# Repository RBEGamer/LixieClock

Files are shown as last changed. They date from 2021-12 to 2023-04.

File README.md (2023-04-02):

# LixieClock

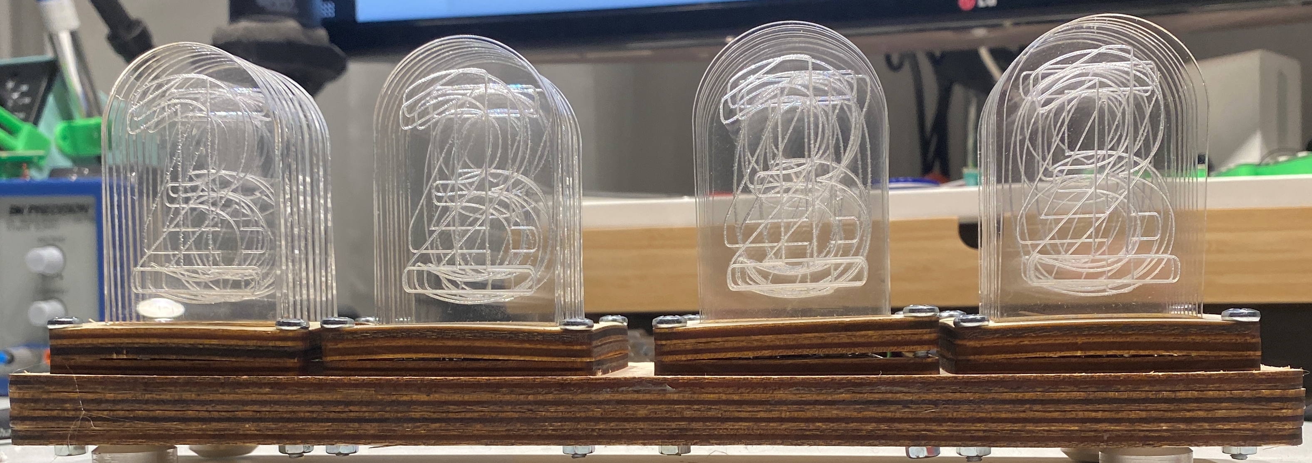
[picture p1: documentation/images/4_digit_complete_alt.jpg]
4_digit_complete_alt


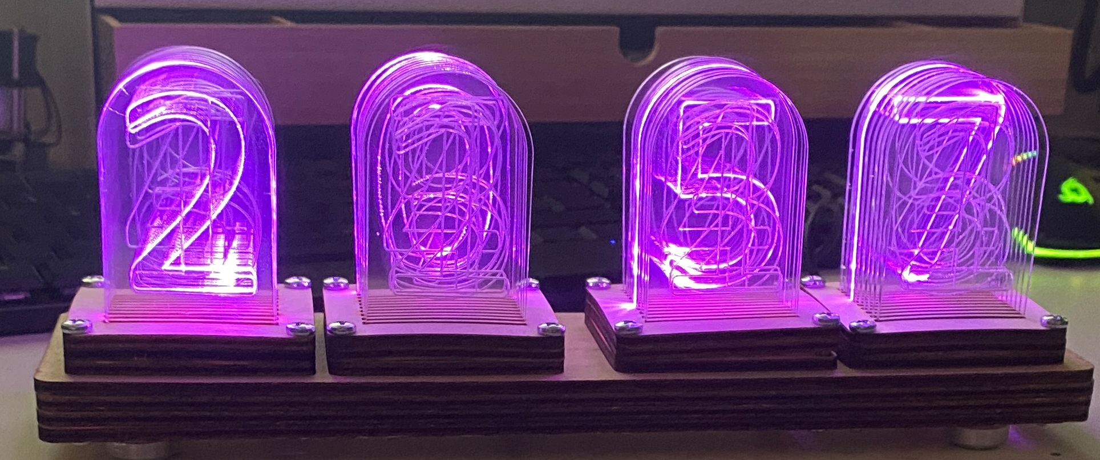
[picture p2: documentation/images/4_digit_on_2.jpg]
4_digit_on_2


# WERKZEUG

* Lötkolben + Lötzinn
* Philips-Kopf Schraubendreher
* Kleine Kabelbilder
* Heißkleber
* Glasreiniger
* Mikro-USB Kabel
* [OPTINAL] Holzkleber

# TEILELISTE

## BILD ZEIGT ALTE REVISION
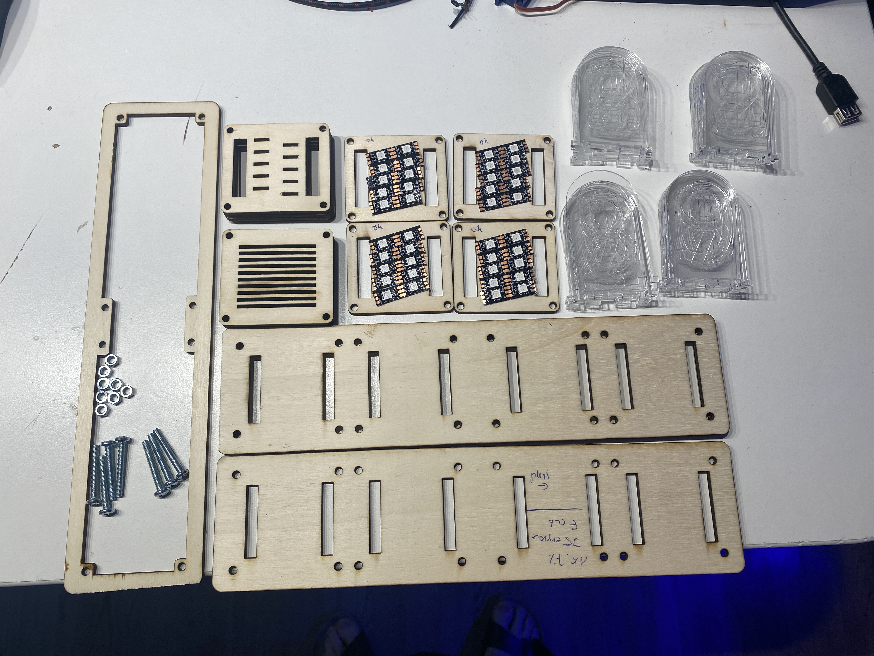
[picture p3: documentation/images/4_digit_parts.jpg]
4_digit_parts


## MECHANICAL

* LASERCUT TEILE `SVG - ./src/svg` oder `DXF - ./src/dxf`
* *  4x `4x_numbers_2mm_set_300_200_simplified` - acrylglas gs 2mm, engrave (blue lines), cut (red lines)
* *  1x `4_digit_combined_set_1` - playwood 4mm, engrave (blue lines), cut (red lines)
* *  1x `4_digit_combined_set_2` - playwood 4mm, engrave (blue lines), cut (red lines)
* *  1x `4_digit_combined_set_3` - playwood 4mm, engrave (blue lines), cut (red lines)

* 3D DRUCK
* * [OPTINAL] 4x `./src/3d_print/4x_lixie_feet.stl` - 0.2mm PLA

* MISC
* * 16x `M4x30 Philips Head Type PH2 - DIN7985`
* * 16x `M4 Nut - DIN934`
* * [OPTINAL] 4x `M4 THREAD INSERTS`

## ELECTRICAL

* 4x `LED_PCB`, SEE `./src/pcb`, LED SEITE BESTÜCKT
* 1x `ESP8266 D1 Mini`
* 8* `1*3 2.54mm  90° MALE HEADERS`
* 4x 3x`Jumperwires FEMALE<=>FEMALE`

## SOFTWARE 

* Arduino IDE

## BUILD INSTRUCTIONS

### 0. PROGRAMMIERUNG BASIS-PROGRAMM

Zum späteren Funktionstest wird hier zuerst der `ESP8266 D1 Mini` programmiert.
Somit kann die vollständige  Funktionalität vor dem finalen Zusammenbau überprüft werden.

Hierzu sollte die Arduino IDE installiert und dieses Git-Repository heruntergeladen sein.
Unter Linux kann dies wie folgt geschehen:

```bash
# ###### LINUX INSTALL ######
$ sudo apt update && sudo apt install -y git xz-utils

# CLONE REPOSITORY
$ cd ~ && git clone https://github.com/RBEGamer/LixieClock ./LixieClock

# INSTALL ARDUINO IDE
# # sudo snap install arduino => SEE NOTE!
$ wget https://downloads.arduino.cc/arduino-1.8.19-linux64.tar.xz
$ tar -xf arduino-1.8.19-linux64.tar.xz
$ cd arduino-1.8.19-linux64 && bash ./install.sh

# ALLOW USB COMMUNICATION
$ sudo usermod -a -G dialout $USER
$ sudo reboot
```

Nach dem Neustart kann der `ESP8266 D1 MINI` per USB Kabel mit dem Computer verbunden werden.

Das Demo-Programm der Uhr, welches eine vollständige über NTP Synchronisierte Uhr darstellt, benötigt einige Bibliotheken.
Diese könne über den Library-Manager der Arduino IDE installiert werden oder aus diesem Repository kopiert werden.
Unter Windows wird der Inhalt des Ordners `./src/required_libs` nach `BENUTZER_VERZEICHNIS/Dokumente/Arduino/libraries` kopiert.

Unter MacOS und Linux befindet sich der `Arduino`-Ordner direkt im Benutzer-Ordner `~/`.
Unter Linux muss aufgepasst werden, wie die Arduino IDE installiert wurde.
Wurde `snap install arduino` verwendet, befindet sich der Library-Order im Snap Verzeichnis `~/.snap/arduino/current/library`.

```bash
# ###### LINUX LIB COPY ######
$ cd ~
$ cp -Rf ./LixieClock/src/required_libs ~/Arduino/libraries
```

Anschließend kann die Arduino IDE geöffnet werden.

Unter `Datei -> Öffnen` kann das Programm geöffnet werden, dies befindet sich in diesem Repository unter dem Pfad `./src/lixieclock/lixieclock.ino`

Unter den Einstellungen muss danach zuerst der Support für den `ESP8266` geladen werden.
Hierzu wird unter dem Punkt `Zusätzliche Boardverwalter-URLs` die folgende Zeile hinzugefügt:

* `https://arduino.esp8266.com/stable/package_esp8266com_index.json`

#### NOTE

Falls ein `ESP32` verwendet wird muss diese hinzugefügt werden:

* `https://raw.githubusercontent.com/espressif/arduino-esp32/gh-pages/package_esp32_dev_index.json`

Allgemein ist die Software mit dem `ESP6266` (nicht `ESP6266-01`) und dem `ESP32` kompatibel.
#### END NOTE

Nach dem Speichern der Einstellungen muss das Board noch installiert werden.
Dazu wird unter `Werkzeuge -> Board -> Boardverwalter` der `ESP8266` installiert.
Anschlißend kann das `LOLIN (WEMOS) D1 MINI (CLONE)` als Board ausgewählt werden.

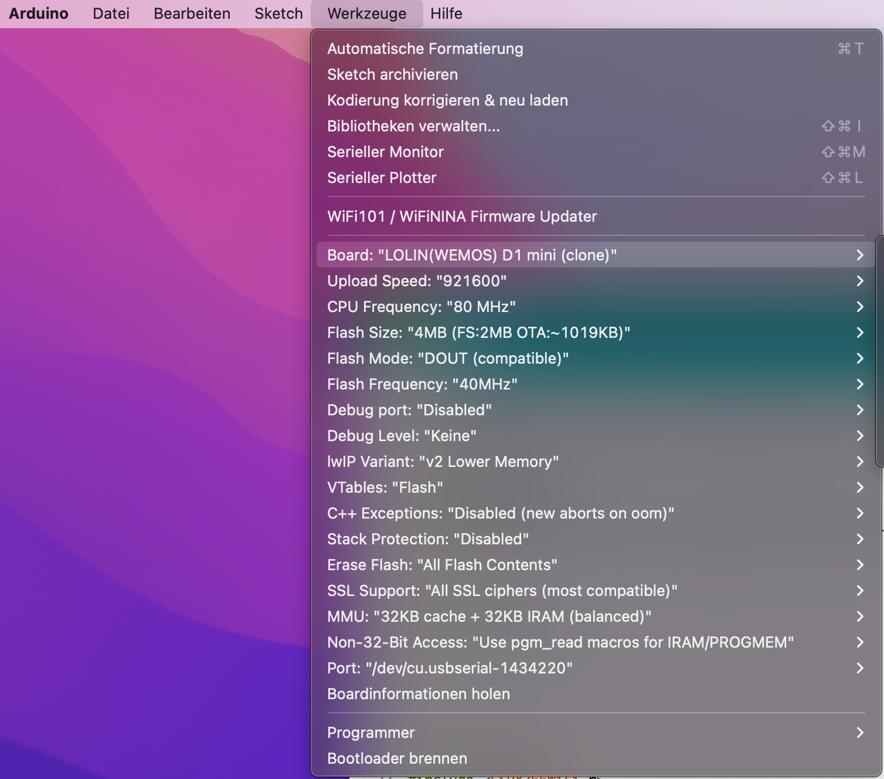
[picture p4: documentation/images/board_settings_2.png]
board_settings


Unter `Port` wird der Serielle-Port ausgewählt, an welchem sich das Board befindet.

* Windows `COMx`
* MacOS `/dev/ttyXXxxxXXxxx`
* Linux `/dev/ttyUSBx`

Anschließend kann über `Sketch -> Hochladen` das Programm hochgeladen werden.

#### NOTE

Im Verzeichnis `./src/lixieclock__base` befindet sich ein Demo-Programm, welches nur die einzelne Segmente ansteuert.
Dies kann als Basis für eigene Projekte verwendet werden.
Mittels der Funktion `update_clock_display` können alle Segmente der Uhr einzeln verändert werden.
Zur Bestimmung der Farbe können die Funktionen `Wheel` und `digit_color` verwendet werden.

```c++
void update_clock_display(int h, int m, int s, int col, int _bright, bool _disable_leading_zero);
uint32_t Wheel(int WheelPos, int _bright);
uint32_t digit_color(int _val,int _index, bool _banked, int _base_color, int _bright);
```

### 1. LED MODULE VORBEREITEN

**HINWEIS: Alle Sperrholzteile sind mit deren Namen markiert. Soweit nicht anders angegeben, zeigt diese nach oben.**

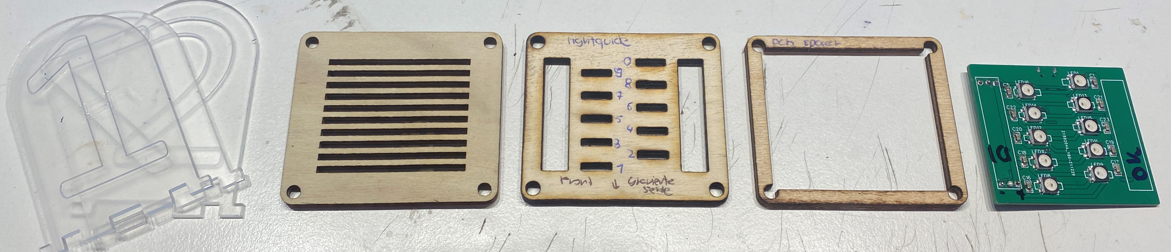
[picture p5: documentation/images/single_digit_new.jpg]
single_digit_new


Jedes LED Modul besteht aus drei Schichten:

* 4x jeweils 10x Acryglas Ziffern
* 4x jeweils 1x Sperrholz Ziffern-Halter
* 4x jeweils 1x Sperrholz Lightguide

Zuerst wird die Schutzfolien von den einzelnen Ziffern entfernt und 
ließend mit Glasreiniger entfettet.
**Ab jetzt dürfen die Ziffern nur noch an den Seiten angefasst werden, denn nach der Montage in der Halterung kommt man nur noch sehr schwer an die inneren Flächen der Ziffern.**

Jetzt werden sie einzelnen Ziffern in den `Ziffern-Halter` eingesetzt. Dabei müssen diese mit der gravierten Seite alle in die gleiche Richtung zeigen.
Auch ist die Reihenfolge wichtig, von hinten nach vorne, sind die Ziffern in dieser Reihenfolge einzusetzen:

`0` - `9`- `8` - `7` - `6` - `5` - `4` - `3` - `2` - `1`  

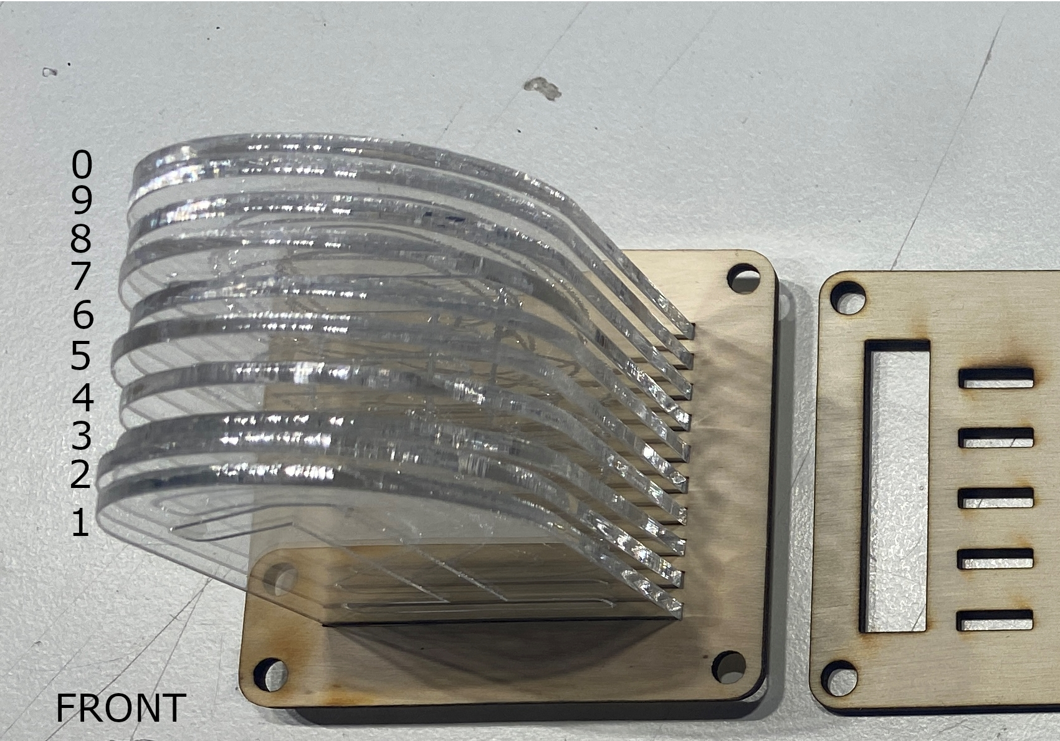
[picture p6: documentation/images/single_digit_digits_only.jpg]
single_digit_digits_only


Anschließend werden die Ziffern auf den `Lighguide` gesetzt.

**Dabei muss die gravierte Seite der Ziffern in Richtung der `FRONT` Markierung zeigen und die Markierungen auf dem `Lightguide` müssen mit den Ziffern übereinstimmen.**

Dieser Prozess, wird für alle vier Ziffern-Blöcke wiederholt.

#### NOTE

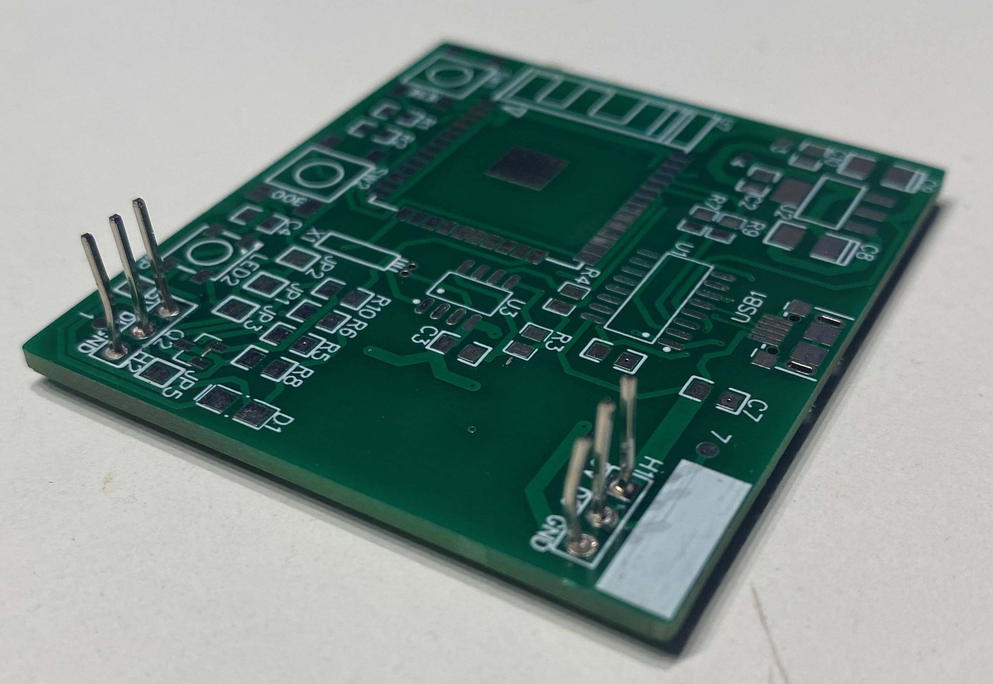
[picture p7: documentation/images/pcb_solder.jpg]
pcb_solder


Sollte bei den vier `LED-PCB`s die zwei Stiftleisten nicht bestückt sein, muss dies zuerst geschehen.
Dazu werden diese in die beiden vorgesehenen 1x3 Pin Bohrungen gesteckt. Diese sind auf der Platine mit `H1` und `H2` beschriftet.
Die lange Seite der Stiftleisten zeigt dabei von der LED Seite weg.

### 2. Zusammenbau Oberseite

Nachdem alle vier Module vorbereitet wurden, können diese nun mit der oberen Bodenplatte zusammengeschraubt werden.
Dabei wird zusätzlich auch die `LED_PCB` und der `PCB Spacer` benötigt.

* 4x PCB Spacer
* 4x LED_PCB mit Bestückter LED Seite
* 4x Top-Cover

Für den Zusammenbau wird das `TOP_COVER` mit der Beschriftung nach oben gelegt und die `LED-PCB`s jeweils mit den Stiftleisten in die Aussparungen des `TOP_COVER` gelegt, sodass die Platine flach aufliegt.

**WICHTIG** Die `FRONT` Markierung auf dem `TOP_COVER` und der Pfeil zeigt dabei zur Tischkante!

Diese werden dadurch nicht flach auf dem Tisch liegen, es empfiehlt sich das `TOP_COVER` dafür auf eine Tasse zu stellen.

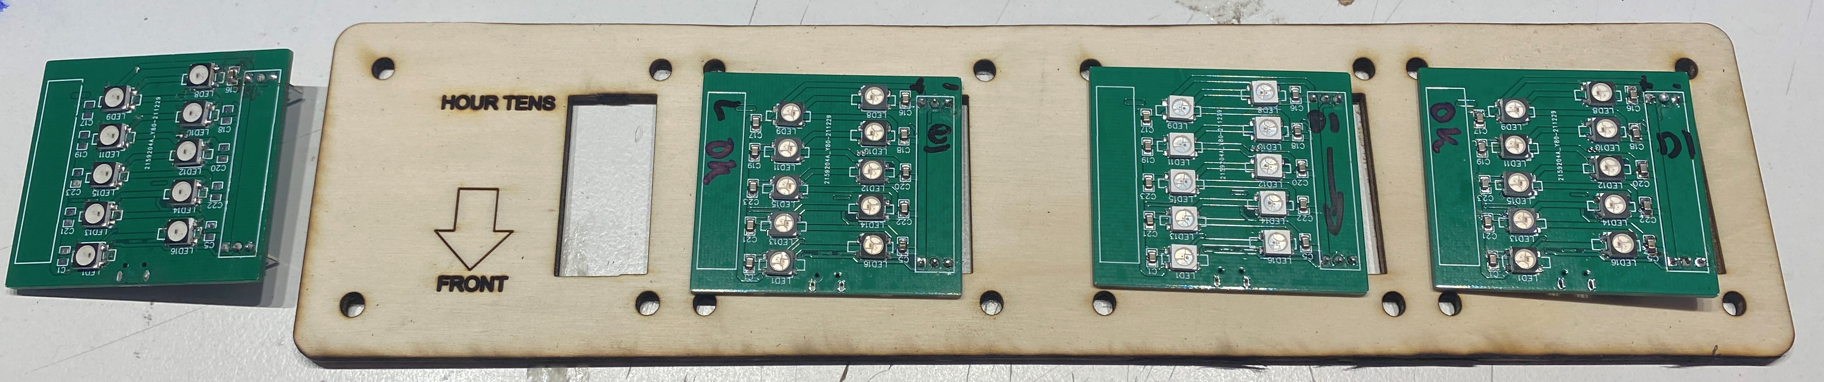
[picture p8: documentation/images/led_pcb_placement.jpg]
led_pcb_placement


Anschließend wird auf jede `LED_PCB` der Sperrholz `PCB_SPACER` gelegt, hier ist die Ausrichtung nicht relevant.

Als letztes, wird das im ersten Schritt zusammengebaute Ziffern-Modul auf den `PCB_Spacer` gesetzt.

**Dabei ist die Ziffer `1` die vorderste Ziffer (richtung der `FRONT` Markierung).**

Nach dem Platzieren der vier Ziffern-Module, sollten diese jeweils mit einer der `M40x30` Schrauben und `M4` Mutter gesichert werden.
Hier reicht es diese nicht fest anzuziehen. Dieser Schritt erleichtert die Montage im folgenden Schritt.

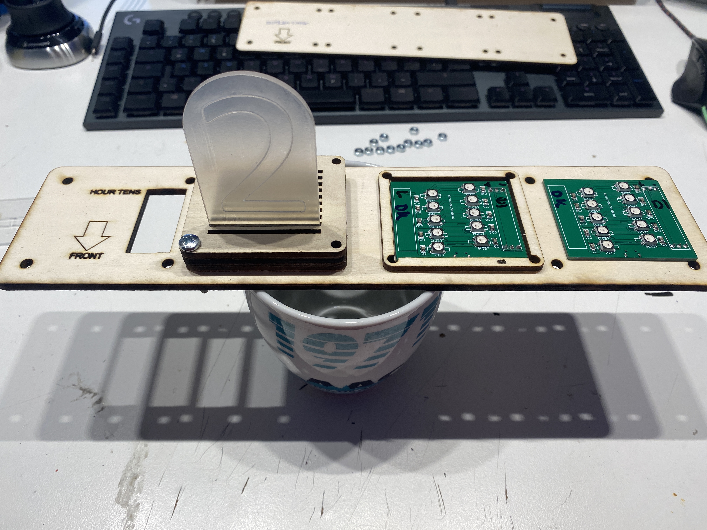
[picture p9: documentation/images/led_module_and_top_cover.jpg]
led_module_and_top_cover


### 3. Montage Bodenplatte

spacers

**Für diesen Schritt, wird alles umgedreht, sodass die LED Module mit der runden Seite auf der Tischplatte stehen.**
Die `FRONT` Markierung sollte jetzt in die andere Richtung Zeigen und somit das LED-Modul welches die Zehner-Stunden darstellen auf der linken Seite befindet.

Hier werden die folgenden Sperrholzteile benötigt:

* 1x `SPACER_TOP`
* 1x `SPACER_BOTTOM`

Diese dienen als Abstandshalter zwischen des `TOP_COVERS` und der Bodenplatte `BOTTOM_COVER`.
Am `SPACER_BOTTOM` befindet sich eine Aussparung für den `ESP8266 D1 MINI`.

#### OPTINAL 
Da diese beiden Teile leicht zerbrechlich sind bietet es sich an, diese mit etwas Holzleim zu verkleben.

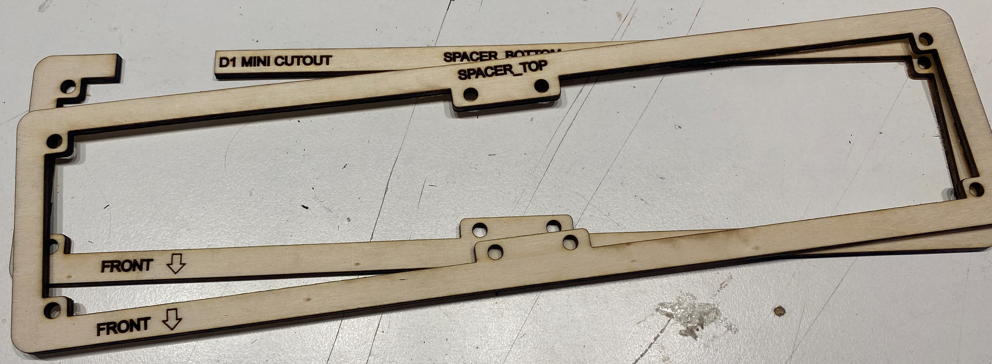
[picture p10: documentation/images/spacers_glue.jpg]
spacers_glue


Dabei wird der  `SPACER_TOP` auf den `SPACER_BOTTOM` geklebt und zu einfachen Arretierung dieser mit zwei Schrauben (oder Wäscheklammern) für 5 Minuten fixiert.
Nach dieser Zeit können diese wieder gelöst werden.

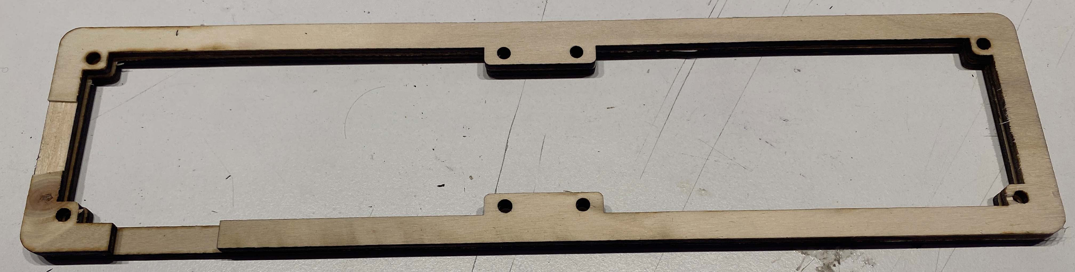
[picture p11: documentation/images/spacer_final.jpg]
spacer_final


#### END OPTIONAL

Die Schrauben (aus Schritt 2), welche die Module gehalten haben können jetzt wieder gelößt werden.

Die beiden Spacer (geklebt oder nicht), werden anschließend auf das `TOP_COVER` gesetzt, sodass sich die Aussparung unten links in der Ecke befindet und sich somit auf der Rückseite der Uhr befindet.
Anschließend können die Module wieder mit je einer Schraube fixiert werden. Somit sollten auch die beiden Spacer fixiert sein.

### 4. Montage Elektronik

Für die Verkabelung und Montage der Elektronik, wird alles umgedreht, sodass die LED Module mit der runden Seite auf der Tischplatte stehen.
Die `FRONT` Markierung sollte jetzt in die andere Richtung Zeigen und somit das LED-Modul welches die Zehner-Stunden darstellen auf der linken Seite befinden.
Für diesen Schritt werden die `Jumper-Wires`, sowie der `ESP8266 D1 MINI` benötigt.

Jetzt werden mit den 4x drei `Jumper-Wires` die einzelnen Module miteinander Verbunden. Auf den `LED-PCB`s sollten die Stiftleisten durch das `TOP_COVER` zugänglich sein. Bei diesen sind die einzelnen Pins beschriftet. Für `H1 => 5V D0 GND` und für `H2 => 5V DIN GND`.
Das Ziel ist es die einzelnen Platinen zu einer Kette zu verbinden. 
Angefangen von der Zehner-Stunden, wird die `H2`-Stiftleiste über drei `Jumper-Wires` mit der `H1`-Stiftleiste des Stunden-Einer-Moduls verbunden.
Dabei wird `5V->5V`, `GND->GND` und `DI->D0` verbunden.
Dieser Prozess wird anschließend noch zweimal wiederholt:

* Stunden-Zehner `H2` => Stunden-Einer `H1`
* Stunden-Einer `H2` => Minuten-Zehner `H1`
* Minuten-Zehner `H2` => Minuten-Einer `H1`

Nach diesem Schritt sind die Stiftleisten `Stunden-Zehner H1` und `Minuten-Einer H2` nicht verbunden.
Im letzten Schritt wird der `ESP8266 D1 Mini` mit der `Stunden-Zehner H1` verbunden.
Dabei werden die folgenden Pins am `ESP8266 D1 Mini` verbunden:

* `(ESP8266 D1 MINI) 5V` => `(Zehner Stunden H1) 5V`
* `(ESP8266 D1 MINI) D8` => `(Zehner Stunden H1) DIN`
* `(ESP8266 D1 MINI) GND` => `(Zehner Stunden H1) GND`

Anschließend kann vor dem finalen Zusammenbau die Funktion getestet werden.
Mit einem USB-Kabel wird der `ESP8266 D1 Mini` verbunden. Jede Ziffer sollte einmal aufleuchten.
Falls dies nicht der Fall ist, ist die Verkabelung zu Prüfen.

Um den Zusammenbau zu vereinfachen, werden die einzelnen Stiftleisten mit dem `Jumperwires` leicht zueinander (ca. 45°) gebogen und mit Heisskleber fixiert.
Auch die Kabel zwischen den Elementen werden mit Kabelbindern und/oder Heißkleber an der `TOP_PLATE` fixiert.

electric_complete

### 5. Endmontage

Im letzten Schritt wird der `ESP8266 D1 Mini` in die Aussparung des Spacers mit Heißkleber geklebt, sodass der USB-Anschluss nach aussen zeigt.
Geklebt wird auf der glatten Seite des `ESP8266 D1 Mini` (auf der gegenüberliegenden Seite des USB-Anschluss).

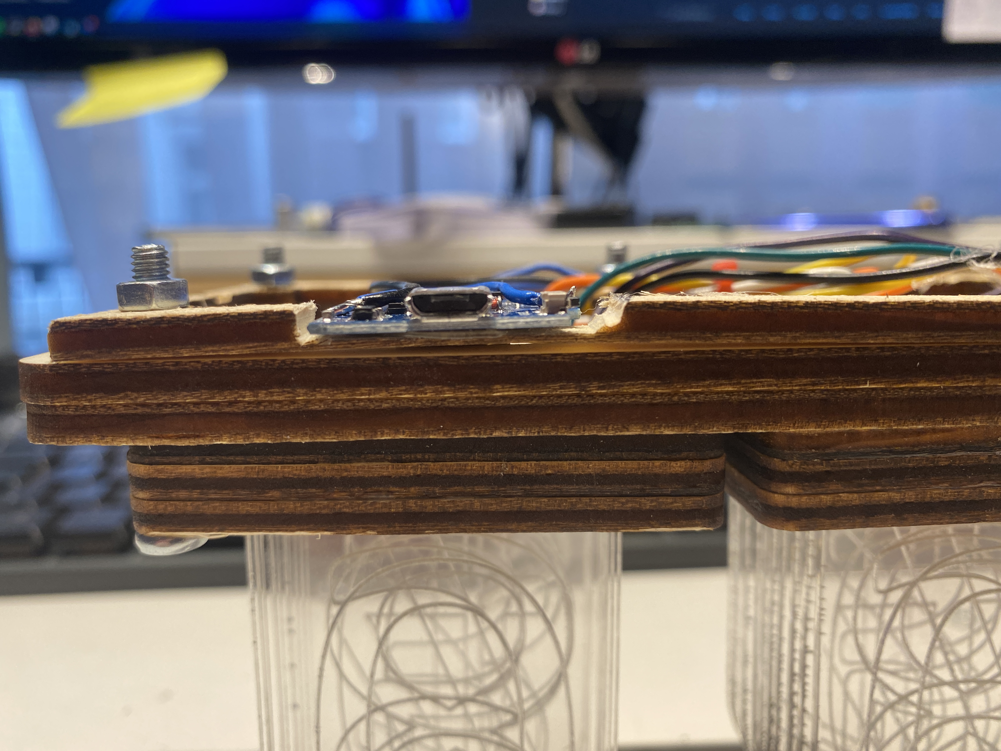
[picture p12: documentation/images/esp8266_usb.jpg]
esp8266_usb


Final kann die Bodenplatte `BOTTOM_COVER` montiert werden. Dazu werden die zuvor zur Montage genutzten Schrauben wieder gelöst und das `BOTTOM_COVER` auf die Spacer gelegt. Alle Schrauben werden dann handfest angezogen.

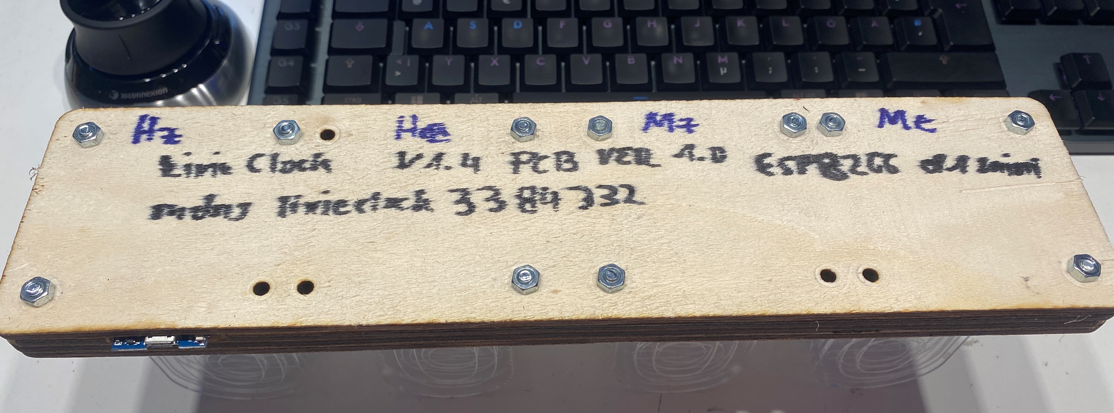
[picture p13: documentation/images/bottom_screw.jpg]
bottom_screw


#### OPTIONAL

Anstatt der vier M4 Muttern an den Ecken können auch die 3D gedruckten Füße angeschraubt werden.
Dazu werden die  `M4 THREAD INSERTS` mit dem Lötkolben erwärmt und in die Bohrung des Fußes bündig einschmelzen.
Nach dem Abkühlen können die Muttern an den Ecken ersetzt werden.

lixie_feet

### 6. Bedienung und Ersteinrichtung

Wenn die Uhr mit dem Basis-Programm programmiert wurde, agiert diese nach dem Starten als NTP-Synchronisierte Uhr.
Hierzu wird ein WLAN benötigt, mit welchem die Uhr einen Zeitserver abgragen kann.
Um dieses WLAN festzulegen, wird die Uhr normal mit Spannung versorgt. Mit einem anderen Endgerät z.B. dem Handy kann sich mit dem WLAN-Access-Point der Uhr verbunden werden.

Die WLAN-Konfigurations-Website ist nach dem Start der Uhr für 120 Sekunden sichtbar.

**Der aktive Access-Point wir vonder Uhr mit `00:00:00` angezeigt!**

Dieses heißt `LixieClockConfiguration_xxXXxxXX`. Nach dem Verbinden mit diesem öffnet sich eine Konfigurationsübersicht, in der das WLAN gesetzt werden kann.
Falls sich die Konfigutationsseite nicht automatisch öffnet (z.B. auf einem PC), kann die IP `http://192.168.4.1/` in einem Browser angegeben werden.

**Achtung** Nur 2.4 Ghz Netzwerke werden vom `ESP8266` und `ESP32` unterstützt.

**Bei einer fehlerhaften Verbindungsaufbau zeigt das Display der Uhr `42:42:42` an.**
Wenn dies der Fall ist, kann die Uhr neugstartet werden und die Konfiguration kann erneut durchgeführt werden.

Nach einer erfolgreichen Verbindung, zeigt die Uhr ihre IP-Adresse auf den einzelnen Ziffern per Laufschrift an.
Wird diese Adresse in einem Browser aus dem gleichen Netz aufgerufen, kann diese umfassend konfiguriert werden.

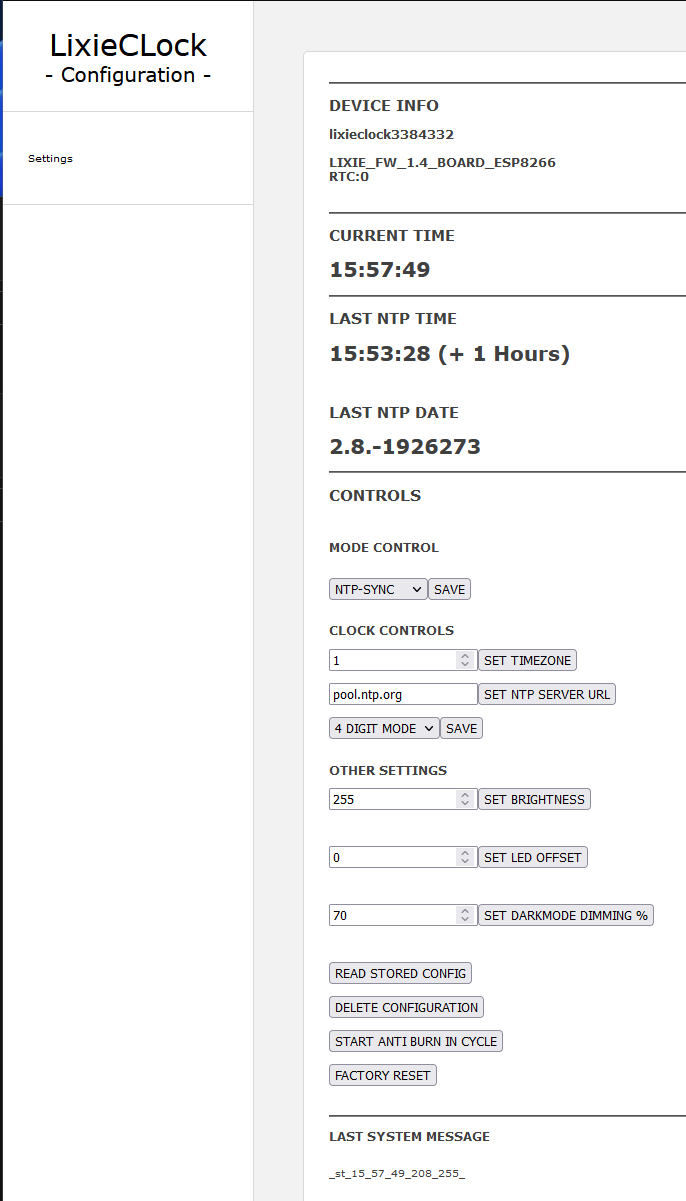
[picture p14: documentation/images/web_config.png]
web_config


# Troubleshooting

## Ziffern 3,4 und 7,8 sind getauscht

Dann hast du eine Platine der ersten Version verwendet. Diese hat einen Fehler in der Platzierung der LEDs bzw. deren Reihenfolge.
Dieser Fehler kann einfach per Software behoben werden. 
In der beigliegenden Demo-Software `/src/lixieclock` und `/src/lixieclock_base` gibt es ein passendes Makro welches gesetzt werden kann.

```c++
10 | #define PCB_V1_FIX //FIX DIGIT 3,4 and 7,8 SWAPPING ERROR ON PCB_V1 
```

## Ziffern sind um eine Stelle vertauscht

Wenn alle Ziffern um eine Stelle nach hinten verschoben ist, dann ist die Entwicklungsversion der Uhr bevor diese als Bausatz konzepiert wurde.
Hier existiert eine Error-LED auf der Platine, somit gibt es eine zusätzliche LED bei der Berechnung des LED-Index.
Hierzu bietet die Software ein Define, welches diesen Fehler behebt.

```c++
9 | #define PCB_V0_FIX //ON THE ESP8266 VERSION OF PCB V0 IS THE ERROR LED PRESENT
``` 

## Wordclock

Die Software-Version `>=2.0` unterstützt zusätzlich die Anordnung der LEDs als `Wordclock`.
Wenn nicht die richtigen Wörter aufleuchten, muss die Software für die Verwendung als Wordclock angepasst werden.

```c++
11 | #define WORDCLOCK_V0 // german wordclock layout
```

## RTC Offline-Mode 

Falls keine Internetverbindung bestehen sollte, kann die Uhr auch im Offline-Modus verwendet werden.
Dazu wird eine RTC Modul `DS1307` oder `DS3231` am I2C Bus des Controllers angeschlossen.
Zusätzlich muss der Software-Support aktiviert werden.
Die RTC wird automatisch durch den NTP-Server gestellt/aktualisiert, wenn eine Internetverbindung vorhanden ist.

```c++
14 | #define ENABLE_RTC
```

## ESP32 Version speichert Konfiguration nicht

Je nach verwendeter Arduino-IDE Version, sowie der verwendeten Libraries kann es bei der ESP32 Software zu Fehlern mit dem Dateisystem FS kommen.
Hierzu gib es eine neue Version `LitteFS`, welche die Default-Version `Filesystem` ersetzt.
Mittels Flag kann erzwungen werden, dass die neue `LittleFS` Bibliothek verwendet werden soll.

```c++
7 | #define USE_LITTLEFS
```

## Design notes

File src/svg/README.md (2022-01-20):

# SVG

This folder contains all svg files for lasercutting all needed peaces for a single digit or a complete clock.

## LASERCUTTING PASSES

* CUTTING `C` RED LINE IN SVG - (K40 SETTINGS 16%, 10mm/s)
* ENGRAVING `E` BLUE LINE IN SVG - (K40 SETTINGS 16%, 40mm/s)

## MATERIAL

* `A` - Plexiglas/Acrylglas GS 2mm
* `P` - Playwood 3mm

## SINGLE DIGIT

* 1x `4x_top_cover` - P, C
* 1x `4x_pcb_spacer` - P, C
* 1x `4x_bottom` - P, C
* 1x `4x_lightguide_top` - P, C
* 1x `4x_numbers_2mm_set_300_200` - A,  E + C

## CLOCK 4 DIGITS
### 200x300mm

* 4x `4x_numbers_2mm_set_300_200` -  A, E + C
* 1x `4_digit_combined_set_1` - P, C
* 1x `4_digit_combined_set_2` - P, C
* 1x `4_digit_combined_set_3` - P, C

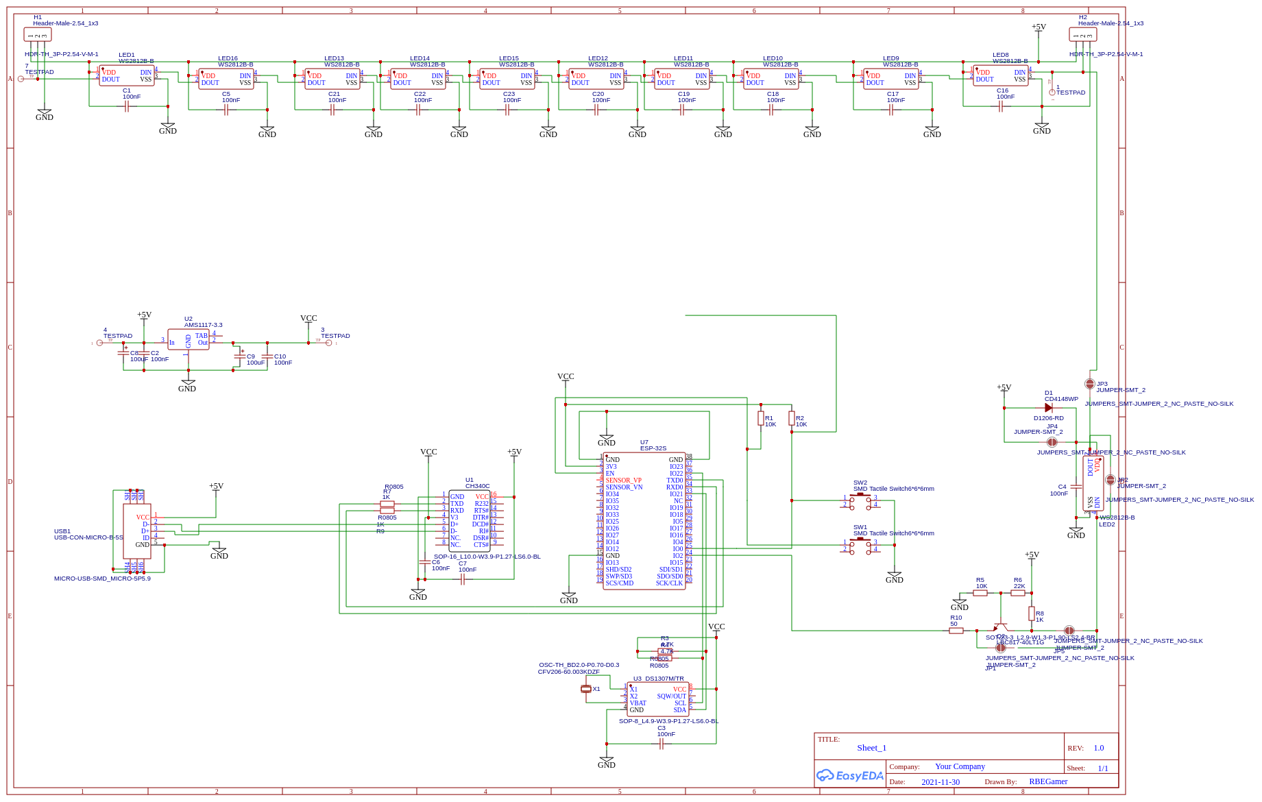
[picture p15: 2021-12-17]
src/pcb/LIXIE_PCB_V1/images/Schematic_LixieClock75x50_2021-12-17.png

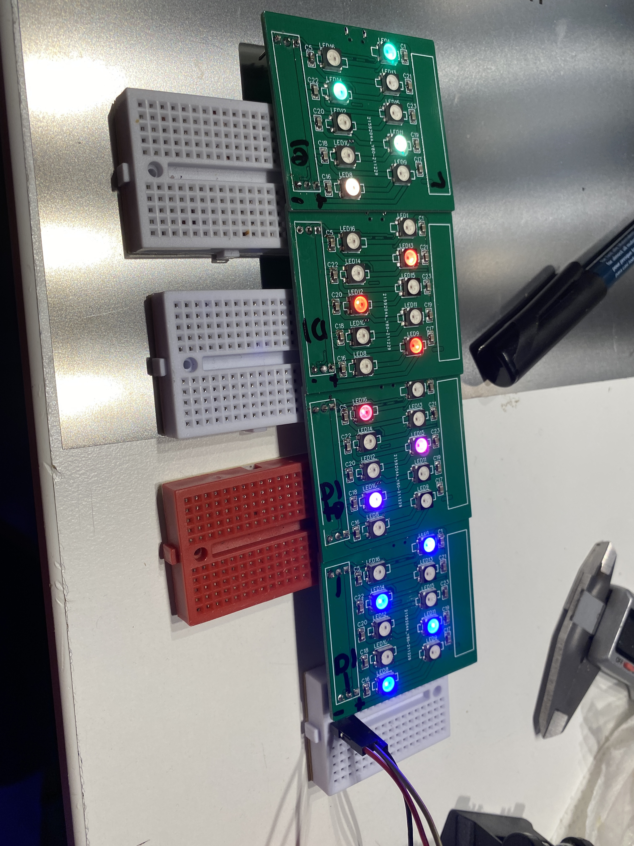
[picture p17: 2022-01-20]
documentation/images/2022-01-08 19.33.17.jpg

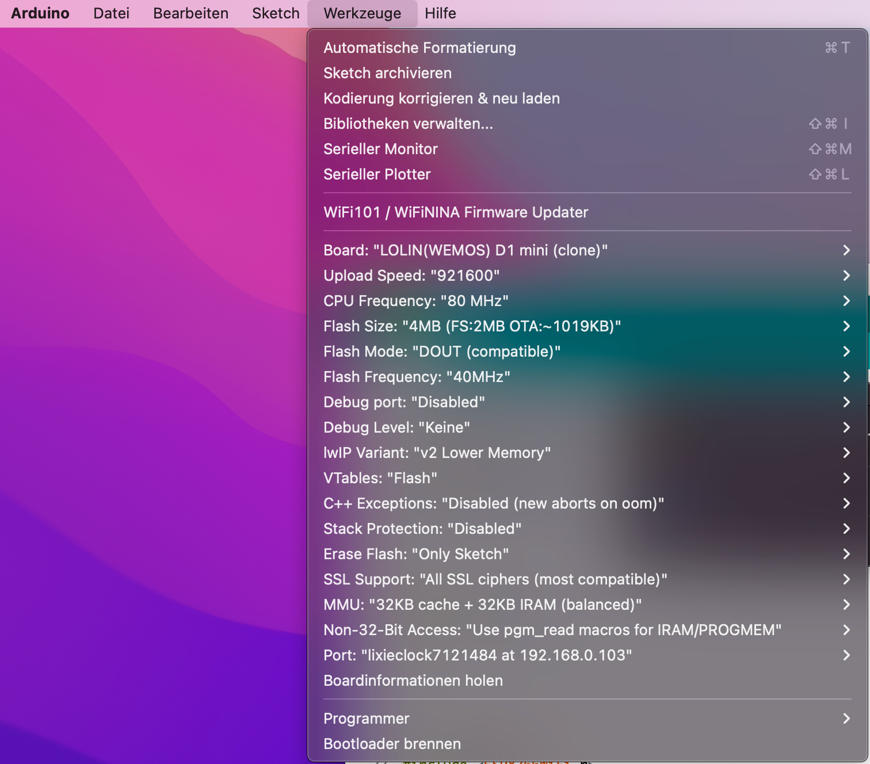
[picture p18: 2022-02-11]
documentation/images/board_settings.png

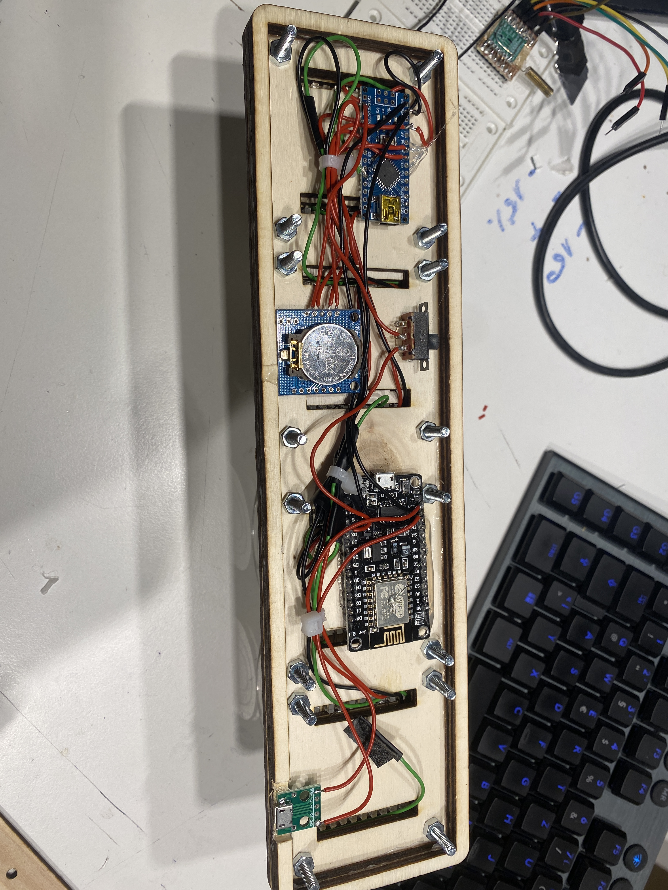
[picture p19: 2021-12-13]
documentation/images/2021-12-09 21.39.20.jpg

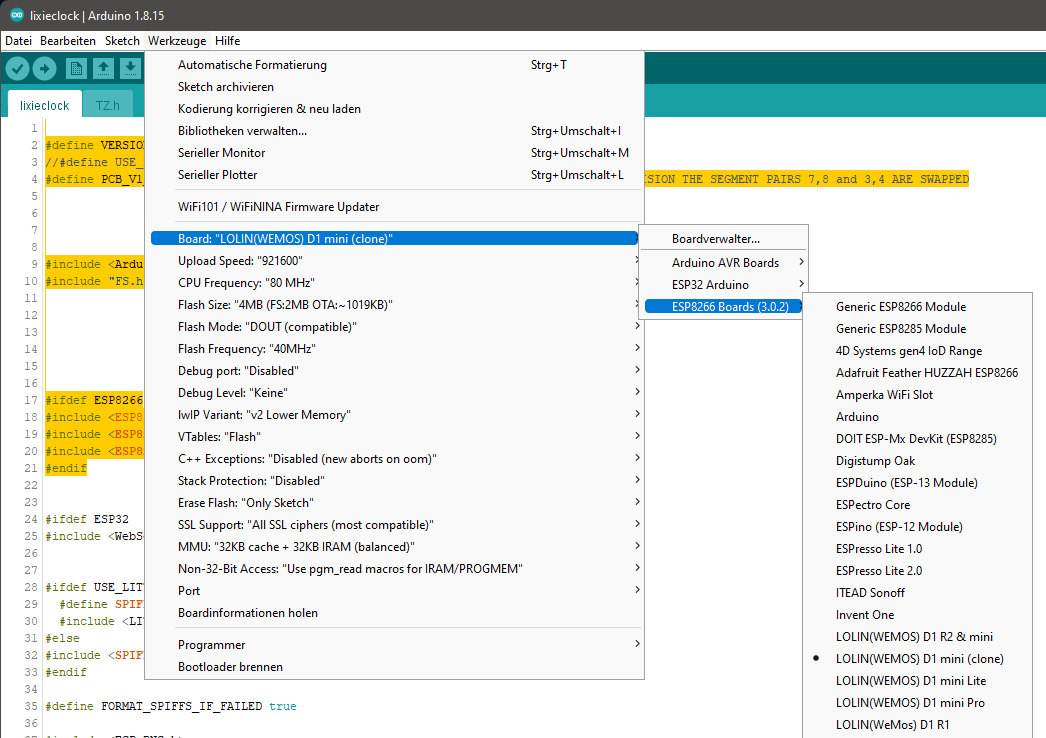
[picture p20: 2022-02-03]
documentation/images/sw_sel_board.png

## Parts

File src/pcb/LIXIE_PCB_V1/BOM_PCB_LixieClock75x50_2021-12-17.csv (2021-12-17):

ID | Name | Designator | Footprint | Quantity | Manufacturer Part | Manufacturer | Supplier | Supplier Part | Price | Pins | 3DModel | JLCPCB Part Class | LCSC Assembly | Contributor | Package Display | SMT Type | image | link
1 | USB-CON-MICRO-B-5S | USB1 | MICRO-USB-SMD_MICRO-5P5.9 | 1 | USB-CON-MICRO-B-5S | ValuePro | LCSC | C40954 | 0.063 | 11 | MICRO-USB-SMD_MICRO-5P5.9 | Extended Part |  | 立创EDA官方封装库 | Yes |  |  | https://item.szlcsc.com/41938.html
2 | TESTPAD | 1,3,4,7 | TESTPAD | 4 |  |  |  |  |  | 1 |  |  |  | Time God
3 | 100nF | C2,C10,C3,C4,C6,C7,C1,C5,C16,C17,C18,C19,C20,C21,C22,C23 | 0805 | 16 | CC0805KRX7R9BB104 | YAGEO | LCSC | C49678 | 0.004 | 2 |  |  | Yes | SparkFun |  | Basic
4 | 10K | R1,R2,R5 | 0805 | 3 | 0805W8F1002T5E | UniOhm | LCSC | C17414 | 0.002 | 2 |  |  | Yes | SparkFun |  | Basic
5 | 22K | R6 | 0805 | 1 | CR0805J22KP05 | Ever Ohms Tech | LCSC | C245415 | 0.002 | 2 |  |  | Yes | SparkFun |  | Basic
6 | 1K | R8 | 0805 | 1 | FCM2012KF-102T04 | TAITEC | LCSC | C155076 | 0.007 | 2 |  |  | Yes | SparkFun |  | Basic
7 | 50 | R10 | 0805 | 1 | 0805W8F1002T5E | UniOhm | LCSC | C17414 | 0.002 | 2 |  |  | Yes | SparkFun |  | Basic
8 | 100uF | C9,C8 | CAP-SMD_L3.5-W2.8 | 2 | TAJB107K006RNJ | AVX | LCSC | C16133 | 0.181 | 2 | CASE-B_L3.5-W2.8-H1.9 |  | Yes | 立创EDA官方封装库 |  | Basic |  | https://item.szlcsc.com/19983.html
9 | Header-Male-2.54_1x3 | H1,H2 | HDR-TH_3P-P2.54-V-M-1 | 2 | Header2.54mm 1*3P | BOOMELE | LCSC | C49257 | 0.013 | 3 | HDR-M-2.54_1x3 | Extended Part |  | 官方封装库 | Yes |  |  | https://item.szlcsc.com/50265.html
10 | AMS1117-3.3 | U2 | SOT-223_L6.5-W3.5-P2.30-LS7.0-BR | 1 | AMS1117-3.3 | AMS | LCSC | C6186 | 0.159 | 4 | SOT-223-4P_L6.5-W3.5-H1.6-LS7.0-P2.30 |  | Yes | 官方封装库 |  | Basic | //image.lceda.cn/szlcsc/C6186.jpg | https://item.szlcsc.com/109711.html
11 | ESP-32S | U7 | WIFIM-SMD_ESP-32S | 1 | ESP-32S | Ai-Thinker | LCSC | C82899 | 3.934 | 39 | WIFIM-SMD_L25.5-W18.0-H3.1-ESP-32S |  |  | LCSC |  |  |  | https://item.szlcsc.com/84060.html
12 | WS2812B-B | LED2,LED1,LED8,LED9,LED10,LED11,LED12,LED13,LED14,LED15,LED16 | LED-5050_4P | 11 | WS2812B-B | Worldsemi | LCSC | C114586 | 0.095 | 4 |  |  |  | LCSC
13 | 1K | R7,R9 | R0805 | 2 | FCM2012KF-102T04 | TAITEC | LCSC | C155076 | 0.007 | 2 | R0805_L2.0-W1.3-H0.6 | Extended Part |  | LCSC | Yes |  |  | https://item.szlcsc.com/142685.html
14 | CH340C | U1 | SOP-16_L10.0-W3.9-P1.27-LS6.0-BL | 1 | CH340C | WCH | LCSC | C84681 | 0.689 | 16 | SOP-16_L9.9-W3.9-H1.5-LS6.0-P1.27 | Extended Part |  | 官方封装库 | Yes |  |  | https://item.szlcsc.com/391677.html
15 | DS1307M/TR | U3 | SOP-8_L4.9-W3.9-P1.27-LS6.0-BL | 1 | DS1307M/TR | HGSEMI | LCSC | C356706 | 0.457 | 8 | SOP-8_L4.9-W3.9-H1.45-LS6.0-P1.27 | Extended Part |  | LCSC | Yes |  |  | https://item.szlcsc.com/383602.html
16 | CFV206-60.003KDZF | X1 | OSC-TH_BD2.0-P0.70-D0.3 | 1 | CFV206-60.003KDZF | CITIZEN | LCSC | C389957 | 0.206 | 2 | OSC-TH_D2.0-W6.0-P0.70 | Extended Part |  | LCSC | Yes |  |  | https://item.szlcsc.com/94424.html
17 | LBC817-40LT1G | Q2 | SOT-23-3_L2.9-W1.3-P1.90-LS2.4-BR | 1 | LBC817-40LT1G | LRC | LCSC | C12767 | 0.017 | 3 | SOT-23-3P_L2.9-W1.3-H1.0-LS2.4-P0.95 | Extended Part |  | 立创EDA官方封装库 | Yes |  |  | https://www.diodes.com/assets/Package-Files/SOT23.pdf
18 | 4.7K | R3,R4 | R0805 | 2 | RMC08054.7K5%N | Tyohm | LCSC | C269733 | 0.004 | 2 | R0805_L2.0-W1.3-H0.6 | Extended Part |  | LCSC | Yes |  |  | https://item.szlcsc.com/142685.html
19 | SMD Tactile Switch6*6*6mm | SW1,SW2 | SW-SMD_4PIN-L6.00-W6.00 | 2 | SMD Tactile Switch6*6*6mm | ReliaPro | LCSC | C23873 | 0.018 | 4 |  |  |  |  |  |  | http://image.lceda.cn/szlcsc/C23873.jpg | https://lcsc.com/product-detail/Tactile-Switches_Made-in-China-6x6x6-6-6-6mm_C23873.html
20 | CD4148WP | D1 | D1206-RD | 1 | CD4148WP | LIZ | LCSC | C109000 | 0.012 | 2 | D1206_L3.2-W1.5-H0.9 | Extended Part |  | 官方封装库 | Yes |  |  | https://item.szlcsc.com/110221.html

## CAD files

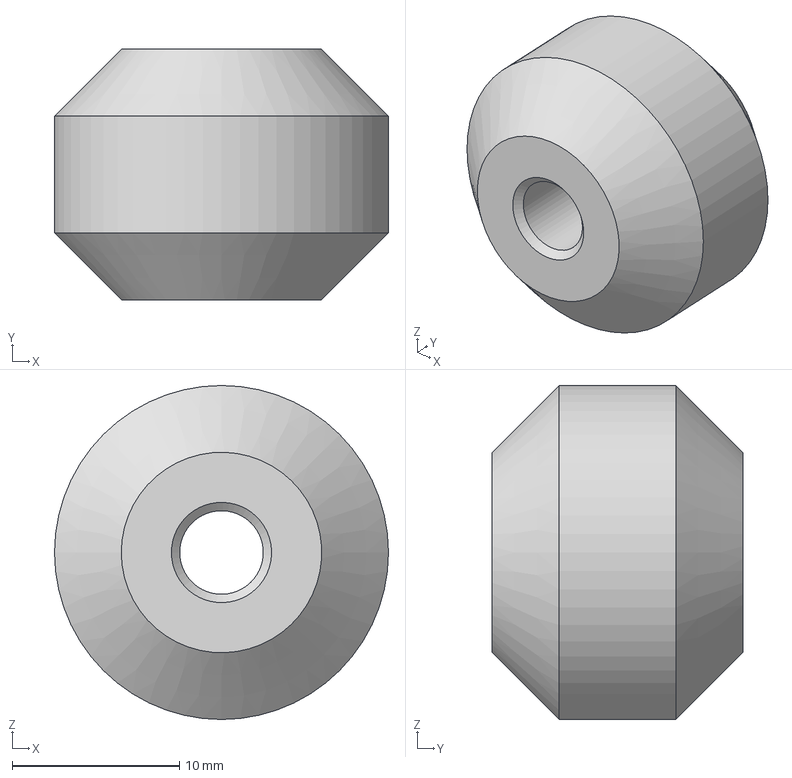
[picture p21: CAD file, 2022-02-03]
src/3d_print/4x_lixie_feet.step
20.0 x 15.0 x 20.0 mm

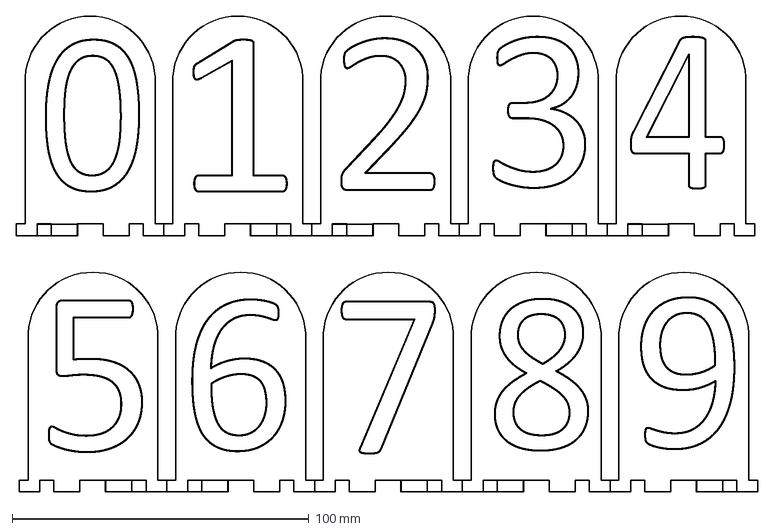
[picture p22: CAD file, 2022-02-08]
src/dfx/4x_numbers_2mm_set_300_200_simplified.dxf
249.7 x 160.3 mm

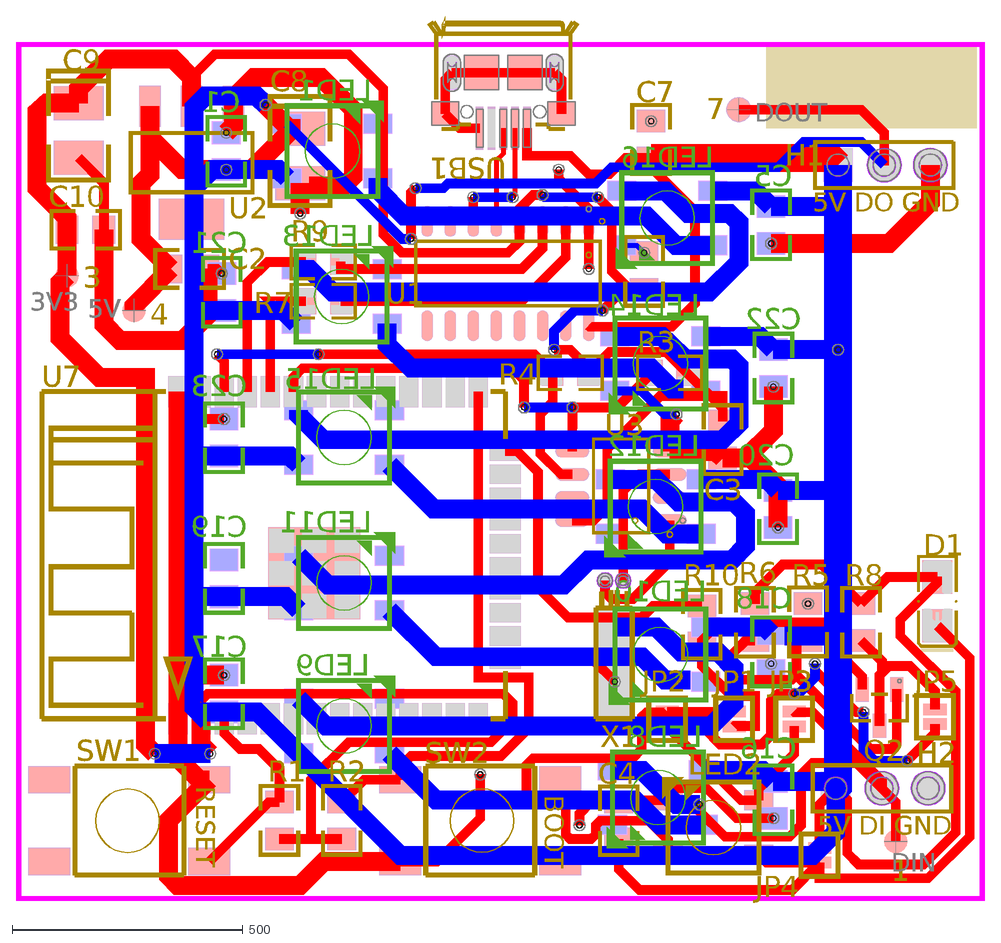
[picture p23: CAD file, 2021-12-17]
src/pcb/LIXIE_PCB_V1/PCB_LixieClock75x50_2021-12-17.dxf
5V DO GND
5V DI GND
RESET
BOOT
USB1
1
DIN
3V3
3
5V
4
7
DOUT
C2
C10
R1
R2
R5
R6
R8
R10
C9
H1
H2
JP1
U2
U7
C3
C4
C7
C8
JP2
LED2
R7
R9
U1
U3
X1
Q2
JP3
R3
R4
SW1
SW2
D1
JP4
JP5
C1
C5
C16
C17
C18
C19
C20
C21
C22
C23
LED1
LED8
LED9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

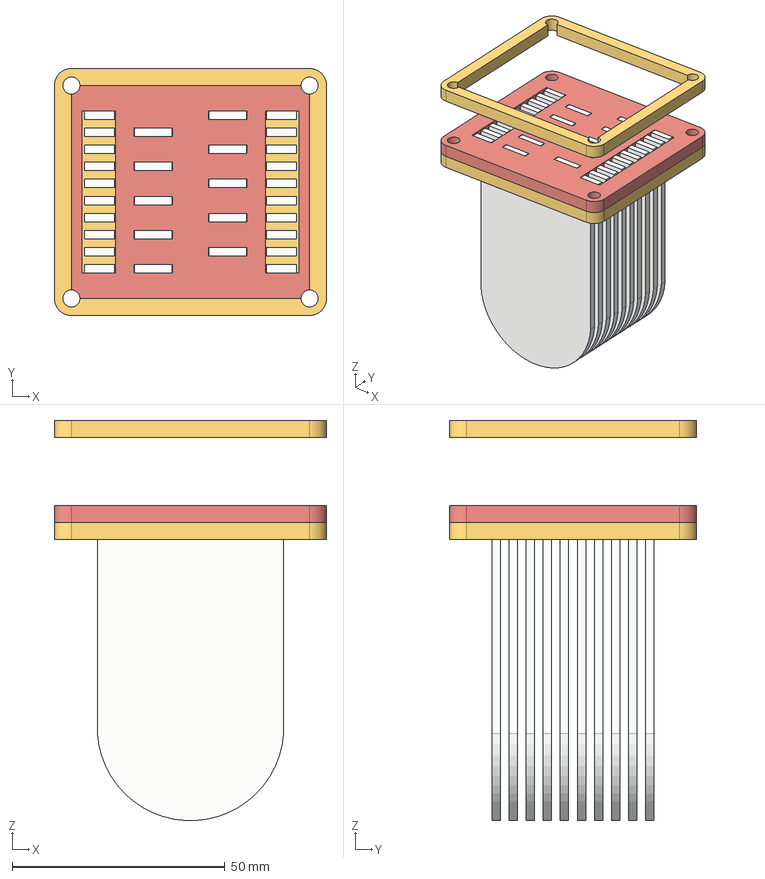
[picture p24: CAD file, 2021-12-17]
src/svg/step/number_base_space_50mm_3mm_2mm v16.step
64.0 x 58.0 x 94.0 mm

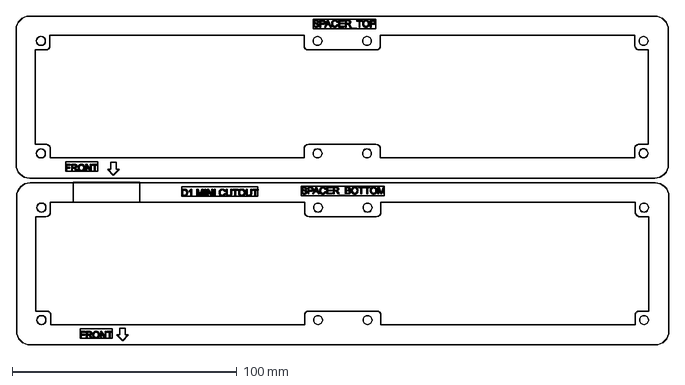
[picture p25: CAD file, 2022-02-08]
src/dfx/4_digit_combined_set_3.dxf
290.3 x 146.2 mm

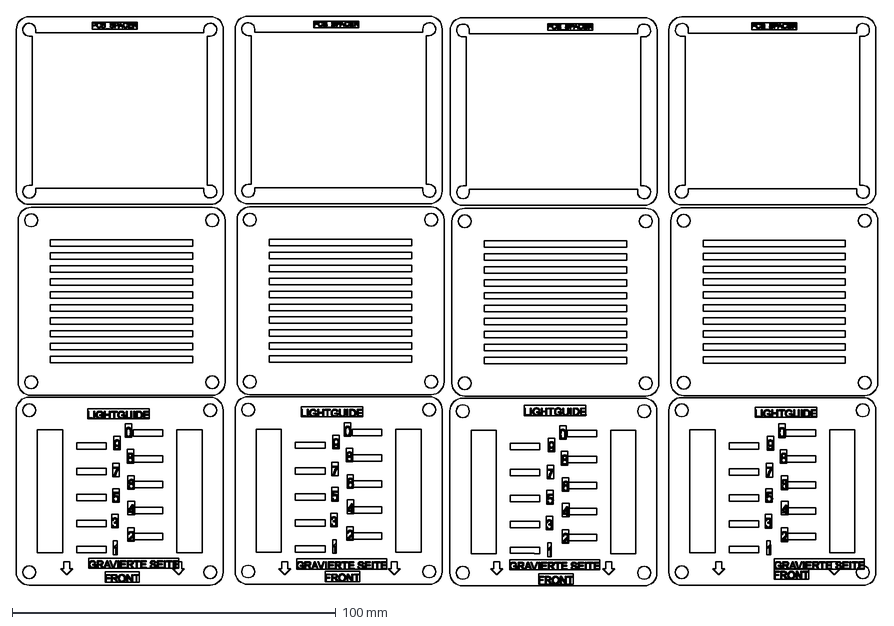
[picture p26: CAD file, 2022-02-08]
src/dfx/4_digit_combined_set_1.dxf
266.2 x 176.0 mm

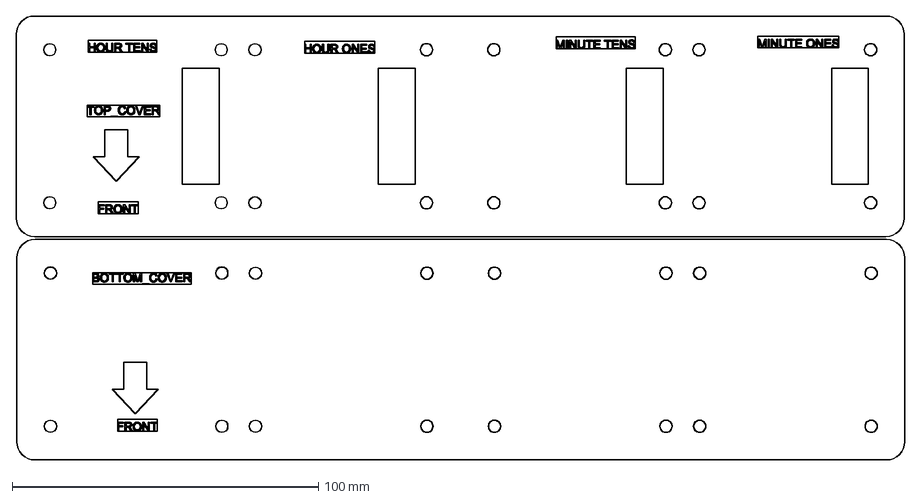
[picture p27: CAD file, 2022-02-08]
src/dfx/4_digit_combined_set_2.dxf
290.2 x 145.0 mm

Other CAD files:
src/3d_print/4x_lixie_feet.3mf
src/3d_print/4x_lixie_feet.f3d
src/3d_print/4x_lixie_feet.obj
src/3d_print/4x_lixie_feet.stl
src/svg/step/number_base_space_50mm_3mm_2mm v16.f3d

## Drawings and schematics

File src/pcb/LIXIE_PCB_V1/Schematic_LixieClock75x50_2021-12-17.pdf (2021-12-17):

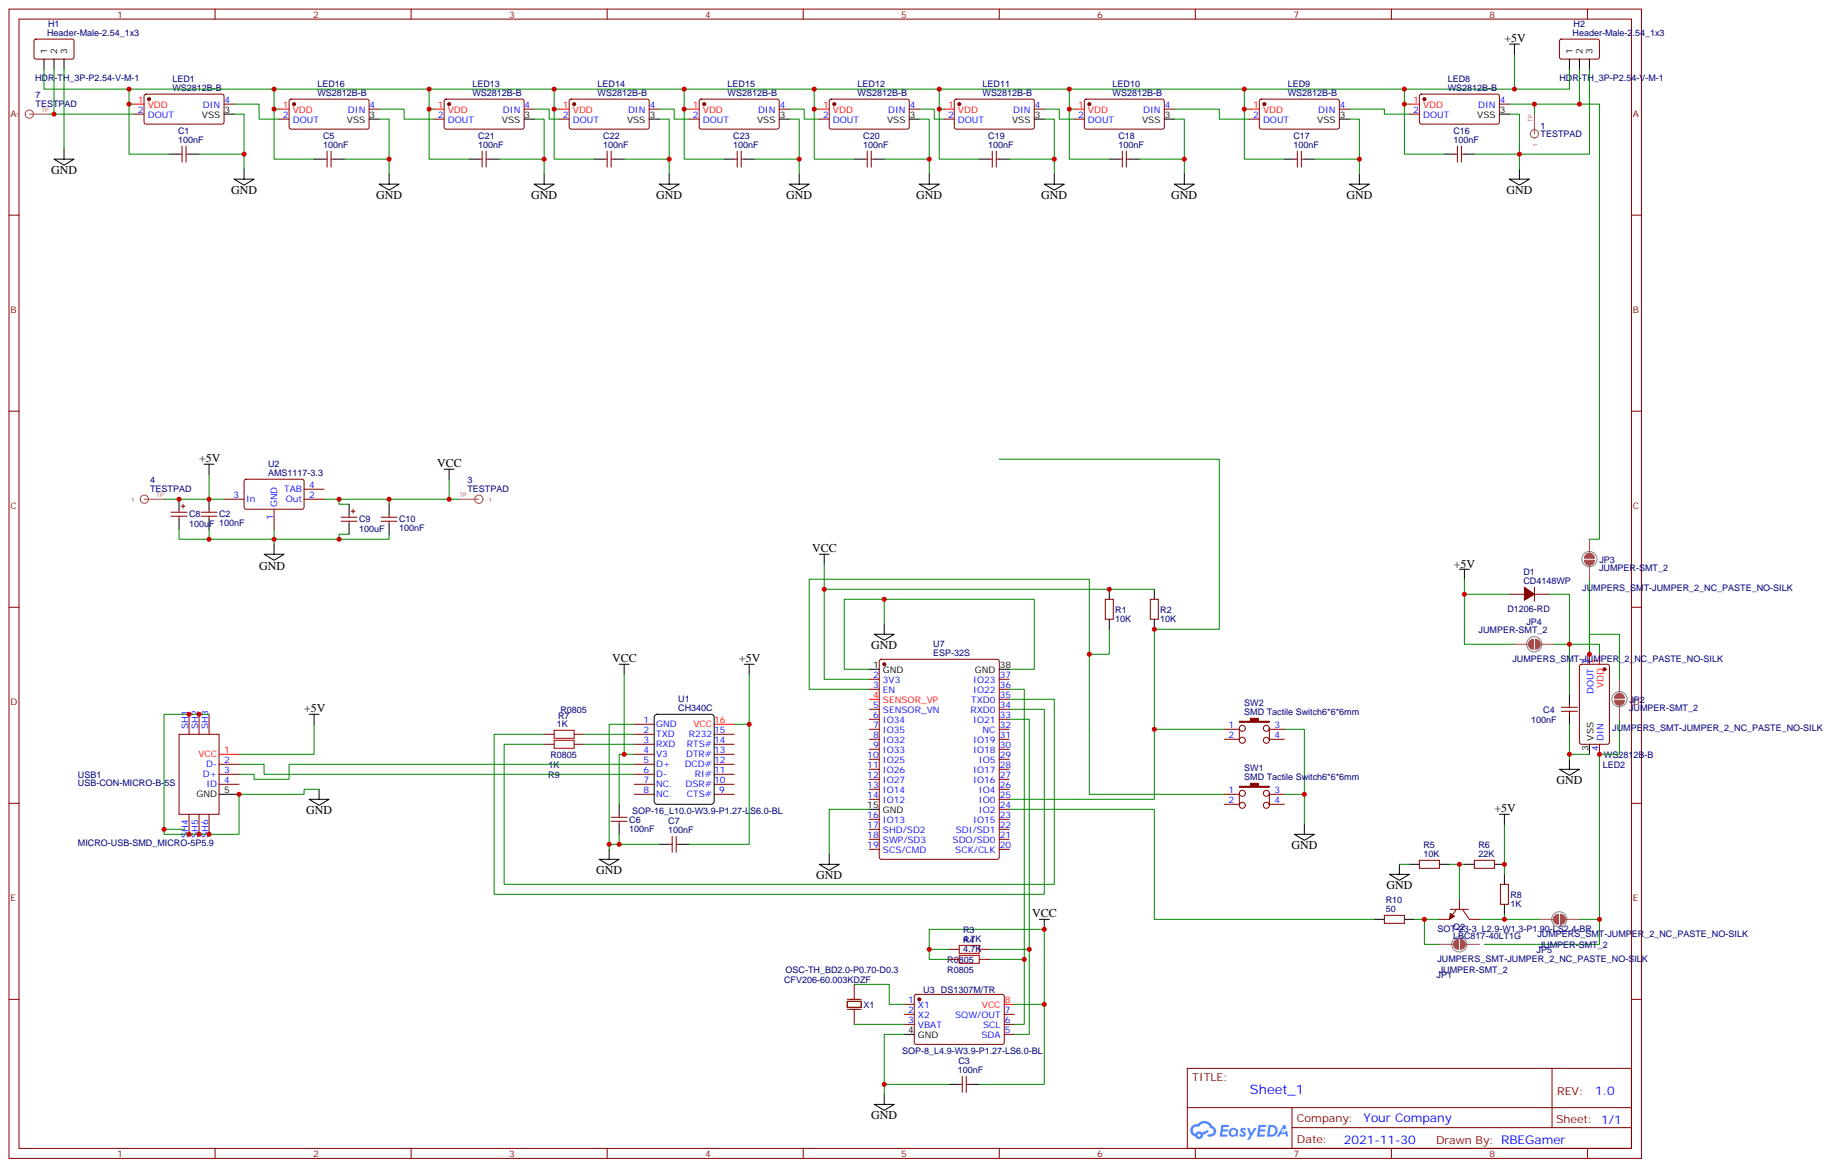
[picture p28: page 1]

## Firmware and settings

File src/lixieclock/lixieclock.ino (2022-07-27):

//FH AACHEN LIXIECLOCK https://github.com/RBEGamer/LixieClock/
//--- CHANGELOG ----
// 12.12.2021 - VERSION 1.0; fixing LED NUMBERING, FIRST STABLE RELEASE
// 10.01.2022 - VERSION 1.4; fixing ESP32 SUPPORT
// 11.02.2022 - VERSION 1.5; fixing SPIFFS INIT AND FORMAT WITH DBG MSG

#define VERSION "2.0"
//#define USE_LITTLEFS
#define PCB_V1_FIX //DEFINE THIS TO AVOID PIXEL ERRORS ON THE PCB V1; ON THIS PCB VERISION THE SEGMENT PAIRS 7,8 and 3,4 ARE SWAPPED
//#define PCB_V0_FIX //ON THE ESP8266 VERSION OF PCB V0 IS THE ERROR ELEMENT PRESENT; SO ONE ADDITIONAL LED IS ADDED
//#define WORDCLOCK_V0


//#define ENABLE_RTC

#include <Arduino.h>
#include "FS.h"




//#ifdef WORDCLOCK_V0
//#include "wordclock_de_constants.h"
//#endif

#ifdef ESP8266
#include <ESP8266WiFi.h>
#include <ESP8266WebServer.h>
#include <ESP8266mDNS.h>
#endif


#ifdef ESP32
#include <WebServer.h>

#define FORMAT_SPIFFS_IF_FAILED true

#ifdef USE_LITTLEFS
  #define SPIFFS LITTLEFS
  #include <LITTLEFS.h>
#else
#include <SPIFFS.h>
#endif
#include <ESPmDNS.h>
#endif



#include <WiFiClient.h>
#include <WiFiUdp.h>
#include <Wire.h>
#include <TimeLib.h>
#include <NTPClient.h>
#include <WiFiManager.h>
#include <WiFiUdp.h>
#include <ArduinoOTA.h>
#include <PubSubClient.h>

#include <Adafruit_NeoPixel.h>
#ifdef __AVR__
 #include <avr/power.h> // Required for 16 MHz Adafruit Trinket
#endif


#include <Wire.h>
#include "RTClib.h"

#if defined(ESP32)
#include "TZ.h"
#elif defined(ESP8266)
#include <TZ.h>
#else
#include "TZ.h"
#endif


#define MYTZ TZ_Europe_London



// CONFIG -------------------------------------
#define WEBSERVER_PORT 80 // set the port for the webserver eg 80 8080
#define MDNS_NAME "lixieclock" // set hostname
#define WEBSITE_TITLE "Lixie Clock Configuration" // name your device
#define SERIAL_BAUD_RATE 9600
#define NTP_SEND_TIME_INTERVAL 5 //sende zeit an uhr all x minuten
#define DEFAULT_NTP_SERVER "pool.ntp.org"
#define DEFAULT_TIMEZONE 1
#define DEFAULT_MQTT_BROKER "192.168.178.89"
#define DEFAULT_MQTT_TOPIC "/iot/9770941/humidity"
#define DEFAULT_MQTT_BROKER_PORT "1883"
#define DEFAULT_MQTT_DISPLAY_MODE 0
#define DEFAULT_BEIGHTNESS 255
#define DEFAULT_DLS 0
#define DEFAULT_DIGIT_ORDER 0
#define DEFAULT_DARKMODE_DIMMING 50
//ON THE ESP32 PCB VERSION IS AN FIRST LED ON THE BOTTOM SIDE OF THE PCB FOR STATUS INDICATION
//SO FOR INDEXING THE CLOCK DIGITS AN OFFSET OF 1 MUST BE ADDED
//IF YOU A RE USING A D1 MINI DIRECTLY CONNECTED TO THE FIST DIGIT LED THE OFFSET IS ZERO
#if defined(ESP32)
#define DEFAULT_LED_OFFSET 1
#elif defined(ESP8266)
#ifdef PCB_V0_FIX

#define DEFAULT_LED_OFFSET 1
#else
#define DEFAULT_LED_OFFSET 0
#endif

#else
#define DEFAULT_LED_OFFSET 0
#endif

// PIN CONFIG -----------------------------------

#ifdef WORDCLOCK_V0
  #define NEOPIXEL_PIN D1
#else

  #ifdef ESP8266
    #define NEOPIXEL_PIN D8
  #endif

  #ifdef ESP32
    #define NEOPIXEL_PIN 4
  #endif

#endif





// END CONFIG ---------------------------------


String time_last = "not synced";


#if defined(ESP8266)
const String BOARD_INFO= "LIXIE_FW_" + String(VERSION) + "_BOARD_" + "ESP8266";
#elif defined(ESP32)
const String BOARD_INFO= "LIXIE_FW_" + String(VERSION) + "_BOARD_" + "ESP32";
#endif


// DARKMODE
const int DARKMODE_START_HOURS = 0;
const int DARKMODE_STOP_HOURS = 6;

    
// NEOPIXEL CONF ------------------------------
#ifdef WORDCLOCK_V0

#define M_ES 0
#define M_IST 1
#define M_FUENF 2
#define M_ZEHN 3
#define M_ZWANZIG 4
#define M_VIERTEL 5
#define M_VOR 6
#define M_NACH 7
#define M_HALB 8
#define M_UHR 21
#define H_EINS 11
#define H_ZWEI 12
#define H_DREI 13
#define H_VIER 14
#define H_FUENF 10
#define H_SECHS 15
#define H_SIEBEN 17
#define H_ACHT 16
#define H_NEUN 9
#define H_ZEHN 19
#define H_ELF 20
#define H_ZWOELF 18
#define H_EIN 22

const int NUM_NEOPIXELS = 10*11;
const int ABI_COUNTER_MAX = 10;
const int COUNT_CLOCK_DIGITS = 2;
const String ap_name = "WordClockConfiguration";
const int WORD_ARR_LEN = 23;
int clockWords[WORD_ARR_LEN][10] = {
  {9,10,-1,-1,-1,-1,-1,-1,-1,-1}, // es 0 X OK
  {5,6,7,-1,-1,-1,-1,-1,-1,-1},  // ist 1 X OK
  {0,1,2,3,-1,-1,-1,-1,-1,-1},  // fuenf 2 X OK
  {11,12,13,14,-1,-1,-1,-1,-1,-1},  // zehn 3 X OK
  {15,16,17,18,19,20,21,-1,-1,-1}, //  zwanzig 4 X OK
  {22,23,24,25,26,27,28,-1,-1,-1},  // viertel 5 X OK
  {33,34,35,-1,-1,-1,-1,-1,-1,-1},  // vor 6 X OK
  {43,42,41,40,-1,-1,-1,-1,-1,-1},  // nach 8 X OK
  {54,53,52,51,-1,-1,-1,-1,-1,-1},  // halb 7 X OK
  {102,103,104,105,-1,-1,-1,-1,-1,-1},  // neun 9  X OK
  {44,45,46,47, -1,-1,-1,-1,-1,-1},  // fuenf 10 X OK
  {55,56,57,58,-1,-1,-1,-1,-1,-1},  // eins 11 X OK
  {65,64,63,62,-1,-1,-1,-1,-1,-1},  // zwei 12 X OK
  {73,74,75,76,-1,-1,-1,-1,-1,-1},  // drei 13 X OK
  {66,67,68,69,-1,-1,-1,-1,-1,-1},  // vier 14 X OK
  {77,78,79,80,81,-1,-1,-1,-1,-1},  // sechs 15 X OK
  {87,86,85,84,-1,-1,-1,-1,-1,-1},  // acht 16 X OK
  {93,94,95,96,97,98, -1,-1,-1,-1},  // sieben 17 X OK
  {88,89,90,91,92,-1,-1,-1,-1,-1}, // zwölf 18 X OK
  {99,100,101,102,-1,-1,-1,-1,-1,-1},  // zehn 19 X OK
  {47,48,49,-1,-1,-1,-1,-1,-1,-1},  // elf 20 X OK
  {109,108,107,-1,-1,-1,-1,-1,-1, -1},  // uhr 21 X X
  {55,56,57,-1,-1,-1,-1,-1,-1,-1},  // eins 11 X OK
};


#else
const String ap_name = "LixieClockConfiguration";
const int COUNT_CLOCK_DIGITS = 6; // 2 4 OR 6 DIGITS ARE SUPPORTED
const int NEOPIXEL_DIGIT_OFFSET = 10;
const int NUM_NEOPIXELS = (COUNT_CLOCK_DIGITS*10) + NEOPIXEL_DIGIT_OFFSET; //10 leds per digit
const int ABI_COUNTER_MAX = COUNT_CLOCK_DIGITS * 6; //COUNT ABI ITERATIONS
//const int led_index_digits[] = {9, 0, 1, 3, 2, 4, 5, 7, 6, 8};

#if defined(PCB_V1_FIX)
const int led_index_digits[] = {0, 9, 8, 7, 6, 5, 4, 3, 2, 1}; //PIXEL INDEX OFFSET FOR EACH DIGIT STARTING AT 0,1 2 3 4 5 6 7 8 9
#else
const int led_index_digits[] = {0, 9, 8, 6, 7, 5, 4, 2, 3, 1}; //PIXEL INDEX OFFSET FOR EACH DIGIT STARTING AT 0,1 2 3 4 5 6 7 8 9
#endif
const int digit_offsets[6] = {0, 10 ,20 ,30, 40, 50}; //HOUR_TENS HOUR_ONES MINUTES_TENS MINUTES_ONES
#endif
// END NEOPIXEL CONF ---------------------------
//FILES FOR STORiNG CONFIGURATION DATA
const char* file_ntp_server = "/file.txt";
const char* file_timezone = "/timezone.txt";
const char* file_syncmode = "/syncmode.txt";
const char* file_mqtt_server = "/mqttbroker.txt";
const char* file_mqtt_topic = "/mqtttopic.txt";
const char* file_mqtt_broker_port = "/mqttbrokerport.txt";
const char* file_mqtt_display_mode = "/mqttdispmode.txt";
const char* file_brightness = "/brightness.txt";
const char* file_dalight_saving_enabled = "/enabledls.txt";
const char* file_led_offset = "/ledoffset.txt";
const char* file_digit_order = "/digitorder.txt";
const char* file_darkmode_dimming = "/darkmode_dimming.txt";
//VARS
int sync_mode = 0;
int timezone = 0;
int brightness = 255;
String ntp_server_url = "";
String mqtt_broker_url = "";
String mqtt_topic = "";
String mqtt_broker_port = "";
int led_offset = 1;

long long last = 0;
long long last_abi = 0;

int rtc_hours = 0;
int rtc_mins = 0;
int rtc_secs = 0;
int rtc_day = 1;
int rtc_month = 1;
int rtc_year = 2020;
int mqtt_hours = 0;
int mqtt_mins = 0;
int mqtt_secs = 0;
//0 FOR 4 DIGIT MODE 1 FOR TWO DIGIT MODE
int mqtt_display_mode = 0;
int rtc_hours_tmp = 0;
bool abi_started = false;
int abi_counter = 0;

int dalight_saving_enabled = 0;
//IS SET TO TRUE IN SETUP IF A RTC CLOCK IS DETECTED
bool is_rtc_present = false;
//USEDE FOR SOFTWARE CLOCK
unsigned long timeNow = 0;
unsigned long timeLast = 0;
int digit_order = 0;
int darkmode_dimming = 50; // %

// INSTANCES --------------------------------------------

#ifdef ESP8266
ESP8266WebServer server(WEBSERVER_PORT);
#endif

#ifdef ESP32
WebServer server(WEBSERVER_PORT);
#endif

WiFiUDP ntpUDP;
NTPClient timeClient(ntpUDP,DEFAULT_NTP_SERVER,0,60000);
WiFiClient espClient;
PubSubClient client(espClient);
Adafruit_NeoPixel pixels(NUM_NEOPIXELS, NEOPIXEL_PIN, NEO_GRB + NEO_KHZ800);
RTC_DS1307 rtc;
WiFiManager wifiManager;






const String phead_1 = "<!DOCTYPE html><html><head><title>";
const String phead_2 = "</title>"
                       "<meta http-equiv='content-type' content='text/html; charset=utf-8'>"
                       "<meta charset='utf-8'>"
                       "<link "
                       "href='http://ajax.googleapis.com/ajax/libs/jqueryui/1.8.16/themes/base/"
                       "jquery-ui.css' rel=stylesheet />"
                       "<script "
                       "src='http://ajax.googleapis.com/ajax/libs/jquery/1.6.4/jquery.min.js'></"
                       "script>"
                       "<script "
                       "src='http://ajax.googleapis.com/ajax/libs/jqueryui/1.8.16/"
                       "jquery-ui.min.js'></script>"
                       "<style>"
                       "html, body {"
                       "  background: #F2F2F2;"
                       " width: 100%;"
                       " height: 100%;"
                       " margin: 0px;"
                       " padding: 0px;"
                       " font-family: 'Verdana';"
                       " font-size: 16px;"
                       " color: #404040;"
                       " }"
                       "img {"
                       " border: 0px;"
                       "}"
                       "span.title {"
                       " display: block;"
                       " color: #000000;"
                       " font-size: 30px;"
                       "}"
                       "span.subtitle {"
                       " display: block;"
                       " color: #000000;"
                       " font-size: 20px;"
                       "}"
                       ".sidebar {"
                       " background: #FFFFFF;"
                       " width: 250px;"
                       " min-height: 100%;"
                       " height: 100%;"
                       " height: auto;"
                       " position: fixed;"
                       " top: 0px;"
                       " left: 0px;"
                       " border-right: 1px solid #D8D8D8;"
                       "}"
                       ".logo {"
                       " padding: 25px;"
                       " text-align: center;"
                       " border-bottom: 1px solid #D8D8D8;"
                       "}"
                       ".menu {"
                       " padding: 25px 0px 25px 0px;"
                       " border-bottom: 1px solid #D8D8D8;"
                       "}"
                       ".menu a {"
                       " padding: 15px 25px 15px 25px;"
                       " display: block;"
                       " color: #000000;"
                       " text-decoration: none;"
                       " transition: all 0.25s;"
                       "}"
                       ".menu a:hover {"
                       " background: #0088CC;"
                       " color: #FFFFFF;"
                       "}"
                       ".right {"
                       " margin-left: 250px;"
                       " padding: 50px;"
                       "}"
                       ".content {"
                       " background: #FFFFFF;"
                       " padding: 25px;"
                       " border-radius: 5px;"
                       " border: 1px solid #D8D8D8;"
                       "}"
                       "</style>";

const String pstart = "</head>"
                      "<body style='font-size:62.5%;'>"
                      "<div class='sidebar'>"
                      "<div class='logo'>"
                      "<span class='title'>LixieCLock</span>"
                      "<span class='subtitle'>- Configuration -</span>"
                      "</div>"
                      "<div class='menu'>"
                      "<a href='index.html'>Settings</a>"
                      "</div>"
                      "</div>"
                      "<div class='right'>"
                      "<div class='content'>";

const String pend = "</div>"
                    "</div>"
                    "</body>"
                    "</html>";

String last_error = "";

// ONLY READ THE FIRST LINE UNTIL NEW LINE !!!!!
String read_file(const char* _file, String _default = "")
{
    File f = SPIFFS.open(_file, "r");
    String tmp = _default;
    if (!f) {
        last_error = "open filesystem file_ntp_server failed";
    }
    else {
        tmp = f.readStringUntil('\n');
        last_error = "read from FS:" + String(_file) + " " + tmp;
    }
    return tmp;
}

void restore_eeprom_values()
{
    ntp_server_url = read_file(file_ntp_server,DEFAULT_NTP_SERVER);
    timezone = read_file(file_timezone, String(DEFAULT_TIMEZONE)).toInt();
    sync_mode = read_file(file_syncmode, "1").toInt();
    mqtt_broker_url = read_file(file_mqtt_server,DEFAULT_MQTT_BROKER);
    mqtt_topic = read_file(file_mqtt_topic,DEFAULT_MQTT_TOPIC);
    mqtt_broker_port = read_file(file_mqtt_broker_port, String(DEFAULT_MQTT_BROKER_PORT));
    mqtt_display_mode = read_file(file_mqtt_display_mode, String(DEFAULT_MQTT_DISPLAY_MODE)).toInt();
    brightness = read_file(file_brightness, String(DEFAULT_BEIGHTNESS)).toInt();
    led_offset = read_file(file_led_offset, String(DEFAULT_LED_OFFSET)).toInt();
    dalight_saving_enabled = read_file(file_dalight_saving_enabled, String(DEFAULT_DLS)).toInt();
    digit_order = read_file(file_digit_order, String(DEFAULT_DIGIT_ORDER)).toInt();
    darkmode_dimming = read_file(file_darkmode_dimming, String(DEFAULT_DARKMODE_DIMMING)).toInt();

}

bool write_file(const char* _file, String _content)
{
    File f = SPIFFS.open(_file, "w");
    if (!f) {
        last_error = "Oeffnen der Datei fehlgeschlagen";
        return -1;
    }
    f.print(_content);
    f.close();
    return 0;
}

void save_values_to_eeprom()
{
    write_file(file_ntp_server, ntp_server_url);
    write_file(file_syncmode, String(sync_mode));
    write_file(file_timezone, String(timezone));
    write_file(file_mqtt_server, mqtt_broker_url);
    write_file(file_mqtt_topic, mqtt_topic);
    write_file(file_mqtt_broker_port, mqtt_broker_port);
    write_file(file_mqtt_display_mode, String(mqtt_display_mode));
    write_file(file_brightness, String(brightness));
    write_file(file_dalight_saving_enabled, String(dalight_saving_enabled));
    write_file(file_led_offset, String(led_offset));
    write_file(file_digit_order, String(digit_order));
    write_file(file_darkmode_dimming, String(darkmode_dimming));
 
}


void write_deffault_to_eeprom(){

            sync_mode = 1;
           timezone = DEFAULT_TIMEZONE;
           ntp_server_url = DEFAULT_NTP_SERVER;
           mqtt_broker_url = DEFAULT_MQTT_BROKER;
           mqtt_broker_port = DEFAULT_MQTT_BROKER_PORT;
           mqtt_topic = DEFAULT_MQTT_TOPIC;
           mqtt_display_mode = DEFAULT_MQTT_DISPLAY_MODE;
           brightness = DEFAULT_BEIGHTNESS;
           dalight_saving_enabled = DEFAULT_DLS;
           led_offset = DEFAULT_LED_OFFSET;
           digit_order = DEFAULT_DIGIT_ORDER;
           darkmode_dimming = DEFAULT_DARKMODE_DIMMING;

           
  save_values_to_eeprom();
}

uint32_t Wheel(int WheelPos, int _bright) {
  
   if(_bright > 255){
      _bright = 255;
    }
 
    if(_bright < 0){
    _bright = 0;
    }
    
 const float brgth_scale = _bright / 255.0;
    
  WheelPos = 255 - WheelPos;
  if(WheelPos < 85) {
    return pixels.Color((255 - WheelPos * 3) * brgth_scale, 0, (WheelPos * 3) * brgth_scale);
  }
  if(WheelPos < 170) {
    WheelPos -= 85;
    return pixels.Color(0, (WheelPos * 3) * brgth_scale, (255 - WheelPos * 3) * brgth_scale);
  }
  WheelPos -= 170;
  return pixels.Color((WheelPos * 3) * brgth_scale, (255 - WheelPos * 3) * brgth_scale, 0);
}





//https://forum.arduino.cc/t/time-libary-sommerzeit-winterzeit/221884/2
boolean summertime_EU(int year, byte month, byte day, byte hour, byte tzHours)
// European Daylight Savings Time calculation by "jurs" for German Arduino Forum
// input parameters: "normal time" for year, month, day, hour and tzHours (0=UTC, 1=MEZ)
// return value: returns true during Daylight Saving Time, false otherwise
{
  if (month<3 || month>10) return false; // keine Sommerzeit in Jan, Feb, Nov, Dez
  if (month>3 && month<10) return true; // Sommerzeit in Apr, Mai, Jun, Jul, Aug, Sep
  if (month==3 && (hour + 24 * day)>=(1 + tzHours + 24*(31 - (5 * year /4 + 4) % 7)) || month==10 && (hour + 24 * day)<(1 + tzHours + 24*(31 - (5 * year /4 + 1) % 7)))
    return true;
  else
    return false;
}

uint32_t get_esp_chip_id() {
#if defined(ESP8266)
  return ESP.getChipId();
#elif defined(ESP32)
  uint32_t chipId = 0;
  for (int i = 0; i < 17; i = i + 8) {
    chipId |= ((ESP.getEfuseMac() >> (40 - i)) & 0xff) << i;
  }
  return chipId;
#else
  return 0;
#endif

}

void mqtt_callback(char* topic, byte* payload, unsigned int length) {

  String tmp = "";
  if(length > 5){
    length = 5;
  }
  for (int i = 0; i < length; i++) {
    tmp += (char)payload[i];
  }
  last_error = "GOT MQTT MSG: " + tmp;

  //IF MQTT DISPLAY IS ENABLES SEND IT TO CLOCK
  if(sync_mode == 2 && tmp != ""){
    float ff = tmp.toFloat();
    if (!isnan(ff)) {
       parse_mqtt_float_to_digits(ff);
    }
  }
}


void mqtt_reconnect() {
  // Loop until we're reconnected
 if(client.connected() || sync_mode != 2) {return;}
    // Attempt to connect
    if (client.connect((MDNS_NAME + String(get_esp_chip_id())).c_str())) {
      last_error = "MQTT CLICNET CONNCTED";
      client.subscribe(mqtt_topic.c_str());
    } else {
      last_error = "MQTT CLCIENT CONECT FAILED WITH" + String(client.state());
  }
}




void parse_mqtt_float_to_digits(float _f){
    int whole = (int)_f;
    int remainder = (_f - whole) * 1000;

    if(whole < 0){
      whole = 0;
    }

    
    const int ones = (whole%10);
    const int tens = ((whole/10)%10);
    const int hundreds = ((whole/100)%10);
    const int thousands = (whole/1000);
    
    //SAVE AS SPLITTED REFORMATTED HOUR MINS VARIABLES

    if(mqtt_display_mode == 0){
      mqtt_hours = thousands*10 + hundreds;
      mqtt_mins = tens*10 + ones;
      mqtt_secs = 0;
    }else if(mqtt_display_mode == 1){
      mqtt_hours = tens*10 + ones;
      mqtt_mins = 0;
      mqtt_secs = 0;
    }
    
}



void update_rtc() {
  if(is_rtc_present){
    rtc.adjust(DateTime(rtc_year, rtc_month, rtc_day, rtc_hours, rtc_mins, rtc_secs));
  }
}

void update_rtc_via_ntp(){
  
  
  //UPDATE RTC IF USED
  rtc_hours = timeClient.getHours();;
  rtc_mins = timeClient.getMinutes();
  rtc_secs = 0;
 

  const unsigned long epochTime = timeClient.getEpochTime();
  const struct tm *ptm = gmtime ((time_t *)&epochTime); 
  rtc_day = ptm->tm_mday;
  rtc_month = ptm->tm_mon+1;
  rtc_year= ptm->tm_year+1900;

  
  update_rtc();

  }



//ANTI BURN IN CYLCE ANIMATION
//LIKE REAL NIXIES
void start_abi(){
//LEGACY SUPPORT
              
   Serial.println("_abi_");
   delay(10);
   abi_counter = ABI_COUNTER_MAX;
   abi_started = true;
}


void loop_abi(){
  if(abi_started && abi_counter <= 0){
   abi_started = false;
   abi_counter = 0;
  }
  //UPDATE CLOCK DISPLAY
  abi_counter--;
  const int c = (abi_counter % 10)*11;
  update_clock_display(c,c,c,0,128,false);
}
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
void loop(void)
{

    //HANDLE SERVER
    server.handleClient();

    


    
    //UPDATE NTP NTP
    if ((millis() - last) > 1000 * 60 * NTP_SEND_TIME_INTERVAL) {
        last = millis();   
        if (sync_mode == 1) {
            //HANDLE NTP
            timeClient.update();
            time_last = timeClient.getFormattedTime(); 
            update_rtc_via_ntp();
        }
    }

      
     //MQTT RECONNECT FUNCTION
    if (!client.connected()) {
      mqtt_reconnect();
    }
    //MQTT LOOP FKT
    if(sync_mode == 2){
      client.loop();
    }
    
     //UPDATE RTC IF THE CLOCK IS PRESENT
     //ELSE SIMPLY USE MILLIS TO KEEP TRACK OF TIME
    if (is_rtc_present && sync_mode == 1) {
      
      DateTime now = rtc.now();
      rtc_hours = now.hour();
      rtc_hours_tmp = now.hour();
      rtc_mins = now.minute();
      rtc_secs = now.second();
     
      rtc_day = now.second();
      rtc_month = now.month();
      rtc_year = now.year();
     
     
     //CHECK SUMMERTIME IF ENABLED
      if(dalight_saving_enabled && summertime_EU(rtc_year, rtc_month, rtc_day, rtc_hours,0)){
       rtc_hours_tmp = rtc_hours + 1;
       if(rtc_hours_tmp >= 24){
         rtc_hours_tmp = (rtc_hours_tmp - 24);
       }
      }
     
     
    }else{
    
      timeNow = millis()/1000;
      rtc_secs = timeNow - timeLast;
      
      if (rtc_secs >= 60) {
        rtc_secs = 0;
        timeLast = timeNow;
        rtc_mins++;
      }
      
      if (rtc_mins >= 60){
        rtc_mins = 0;
        rtc_hours++;
      }
      if (rtc_hours >= 24){
        rtc_mins = 0;
        rtc_hours = 0;
      }
      rtc_hours_tmp = rtc_hours;
    }
     
      
    //UPDATE CLOCK DISPLAY
  
    // SET DISPLAY CLOCK
    if (sync_mode == 1 && !abi_started) {
      int tmp_brightness = brightness;
      //APPLY DARKMODE
      if(rtc_hours_tmp >= DARKMODE_START_HOURS && rtc_hours_tmp < DARKMODE_STOP_HOURS){
        tmp_brightness = (int)(tmp_brightness * (1.0 - ((darkmode_dimming % 100) / 100.0)));
      }
      if(tmp_brightness < 10){
        tmp_brightness = 10;
       }
      update_clock_display(rtc_hours_tmp, rtc_mins, rtc_secs, map(rtc_secs,0,60,0,255), tmp_brightness, false);
      
      //MQTT
    }else if (sync_mode == 2 && !abi_started) {
      update_clock_display(mqtt_hours, mqtt_mins, mqtt_secs, map(mqtt_mins,0,99,0,255), brightness, true);

      //OFF
    }else if(sync_mode == 0){
      update_clock_display(0, 0, 0, 0, 10, true);
    }else{
     
      //HANDLE ABI CYLCE
      if ((millis() - last_abi) > 1000) {
        last_abi = millis();   
        loop_abi();
      }
        
    }
 
   
 
    //HANDLE OTA
    ArduinoOTA.handle();
   
 
    delay(70);
}

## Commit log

2021-12-15 fix mqtt; added offset led
2021-12-17 added pcb
    [BOM_PCB_LixieClock75x50_2021-12-17.csv, PickAndPlace_PCB_LixieClock75x50_2021-12-17.csv]
2021-12-29 working littlefs
    [partitions.csv, partitions_custom.csv]
2022-02-03 added altium
    [lixie.pcbdoc, lixie.schdoc]
